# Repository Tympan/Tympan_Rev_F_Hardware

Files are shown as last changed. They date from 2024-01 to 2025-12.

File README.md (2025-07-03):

# Tympan Rev F Hardware
Tympan Rev F Hardware Design Files For First Production Run, Februrary, 2024.

Tympan is Certified Open Source Hardware!

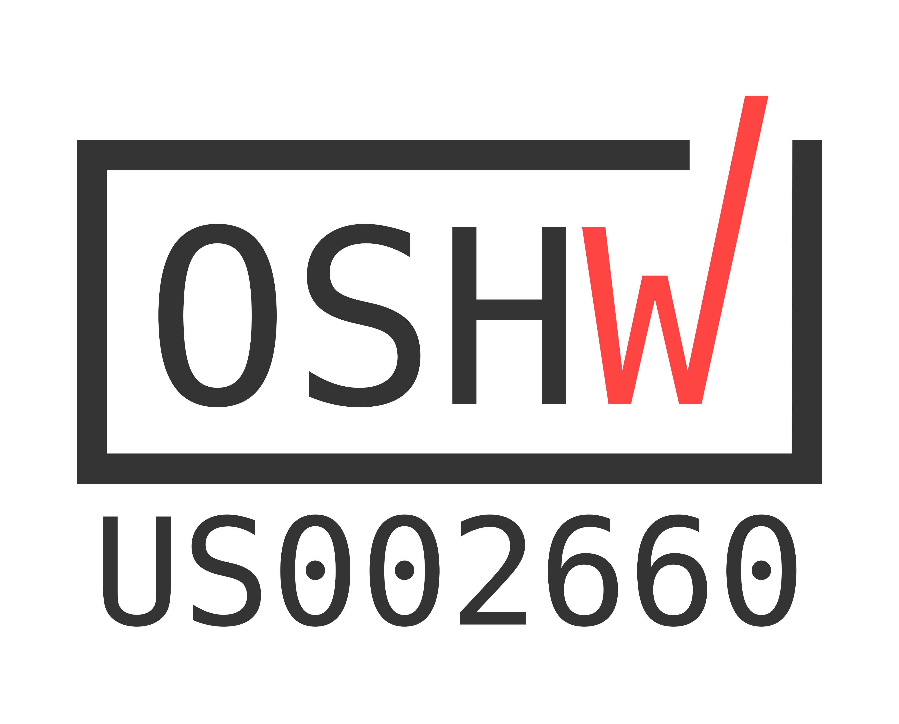
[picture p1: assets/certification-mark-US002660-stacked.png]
Certification Mark


## Changes From Rev E
For the most part, the design of Rev F is a clone of Rev E. The primary challenge of producing Rev E is that the BC127 BLE Radio module we used is not longer available (Product End Of Life). Here are the major changes in the hardware

- Changed to nRF52840 BLE Radio Module
	- Using part number MDBT50Q-1MV2 from Raytac
	- Module requires bootloader, we use Adafruit Feather nRF52840 Express bootloader
	- Bootloading blank module proceedure see below
- nRF52 does not support analog audio, but evidence exists that it can use I2S
	- I2S connections between Teensy 4.1 and nRF52 on I2S_2 pins
- UART coms with the BC127 were slower than desired
	- The SPI_1 bus is connected to nRF module for higher speed
	- The UART pins are still connected and the default speed is now 115200 bps (instead of earlier Tympan's defaulting to 9600)

# Pinout of Expansion Headers

Like all previous Tympan revisions, the Rev F has expansion headers to allow the addition of add-on boards, such as the Tympan AIC shield.  The pinout for the expansion headers is identical for Rev F as for previous Tympan revisions.  The pinout is shown in the [schematic](https://github.com/Tympan/Tympan_Rev_F_Hardware/blob/main/Tympan_Rev_F/Tympan_Rev_F_schematic.pdf) as headers P1 through P4.  You can also see the pinout below.





# Programming The Radio Module

## Over The Air Firmware Updates
Any updates to the application software can be done over Bluetooth using Over The Air Device Firmware Update (OTA DFU). This tutorial will use Adafruit's Bluefruit Connect app, which is available for iPhone and Android.

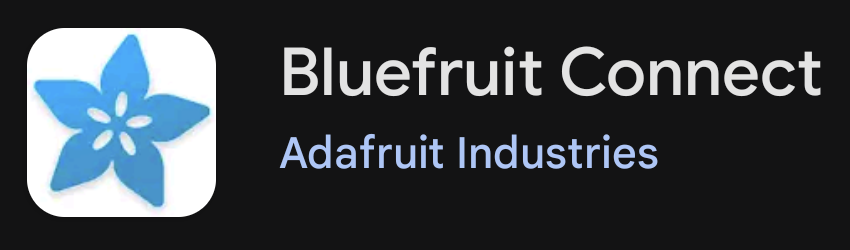
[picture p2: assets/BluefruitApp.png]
Bluefruit App


You will also need two files to upload which Arduino makes when. One is the `.hex` file, The other is a `.dat` file. The latest version of our Tympan Radio firmware is published as a release on this repository, which you can download [HERE](https://github.com/Tympan/Tympan_Rev_F_Hardware/releases/latest) The link will take you to the latest release of the firmware. Download the .ZIP file that is linked there. Both of these files need to be accessible on the phone, or tablet, that you intend to use to perform the OTA DFU. When you have the files on your mobile device, open up the Bluefruit App, and connect to the Tympan that you want to update. Each Tympan advertises it's name followed by a unique ID. Click on connect.

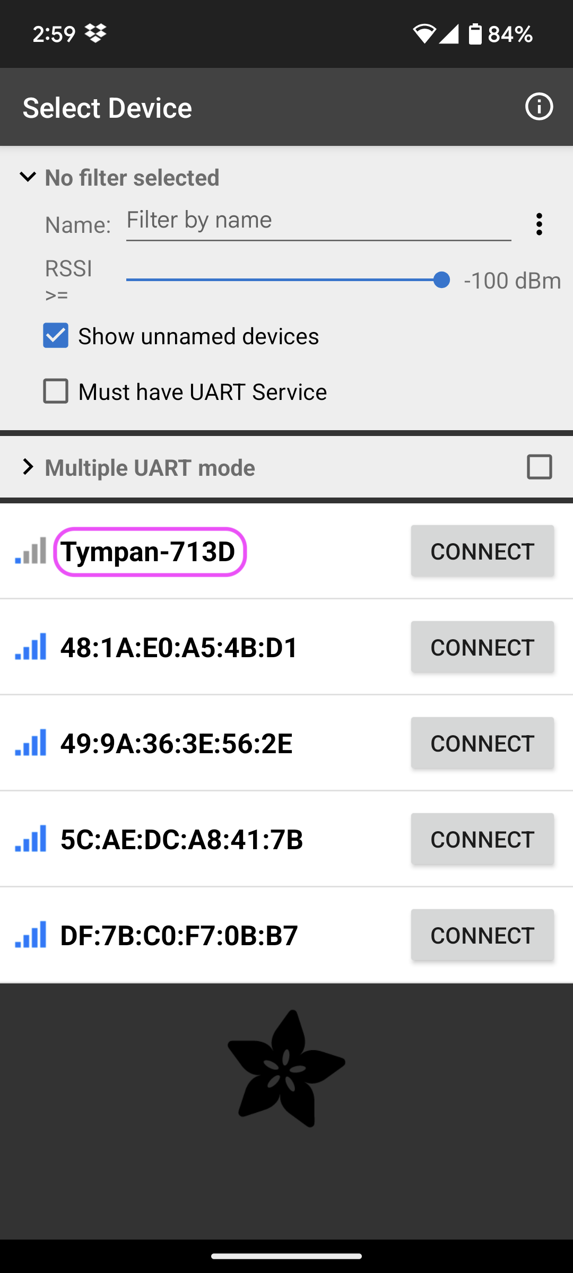
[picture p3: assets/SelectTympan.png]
Connect to Tympan


After connecting, the app will show you various tools. Scroll to the bottom and select the Updates tool.

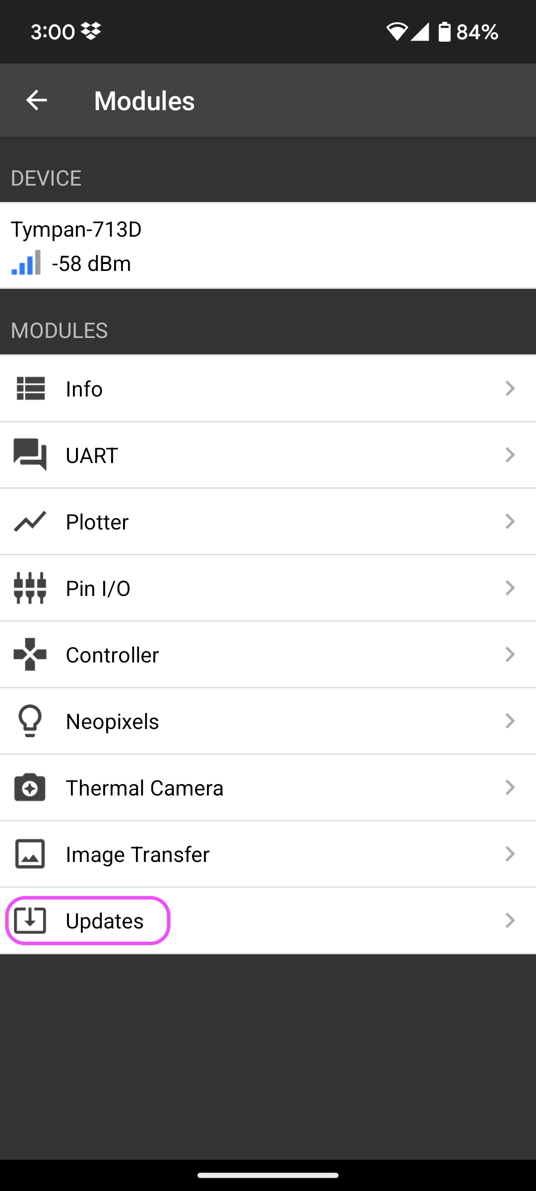
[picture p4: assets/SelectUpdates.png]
Select Updates


There is a long list of updates that are for Adafruit's BLE products. Scroll all the way to the bottom and select Custom Firmware.

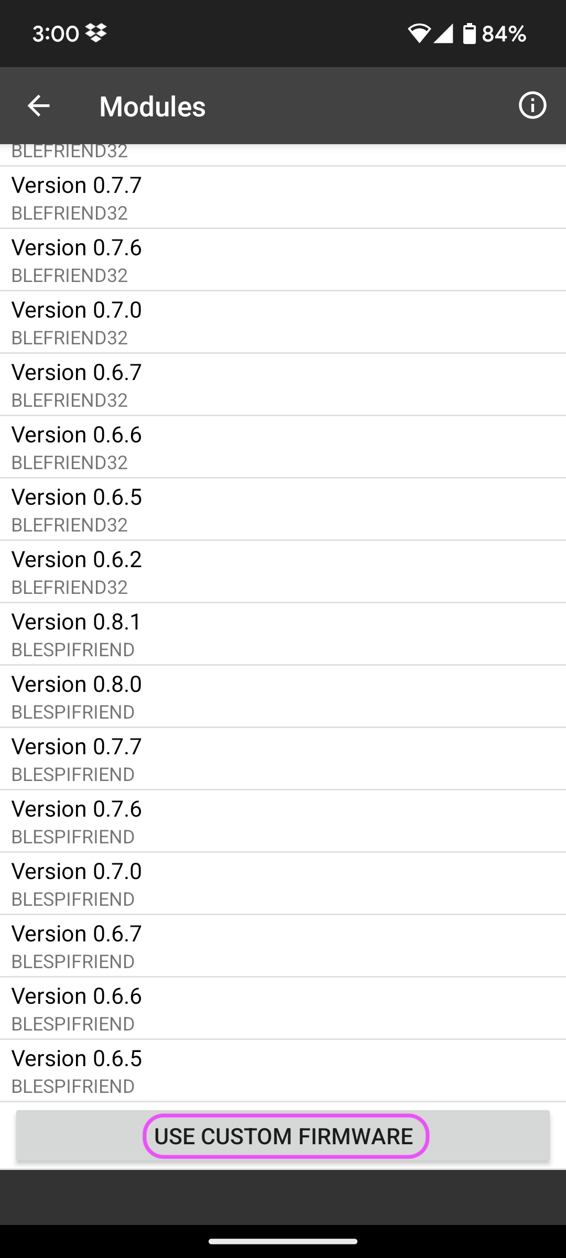
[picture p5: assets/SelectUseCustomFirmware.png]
Select Custom Firmware


The pop-up window will ask you to choose the Hex and Init files. Navigate to the place where you have stored the files you downloaded from our latest release. Choose our hex file for the .hex, and our dat file for the Init file. When you press START UPDATE, the process will begin, and the upload will show a progress bar.

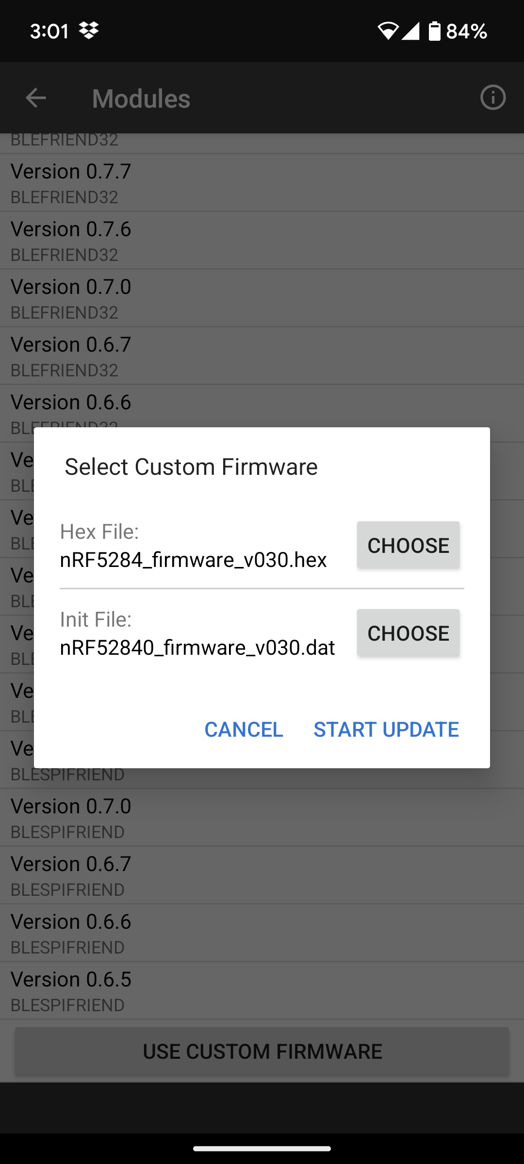
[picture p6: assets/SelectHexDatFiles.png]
Upload Progress


That's it! After successful upload, your Tympan Radio will be running the latest and greatest firmware version. If you want to continue to use the Bluefruit App, it is advised to close the close it after the upload process is complete, and then restart if you intend to use it again right away.

# Wired Firmware Updates

**NOTE: This method is included here for completion. OTA DFU should suffice of all updates**

The blank nRF52 module is programmable using the j-Link connection on pins SWO, SWCLK, SWDIO, RESET, 3V3, and GND. Those module pins are broken out to a header row on the bottom of the board. See connector J7 in the schematic, and the 6 SMT pads on the back layer of the PCB design.

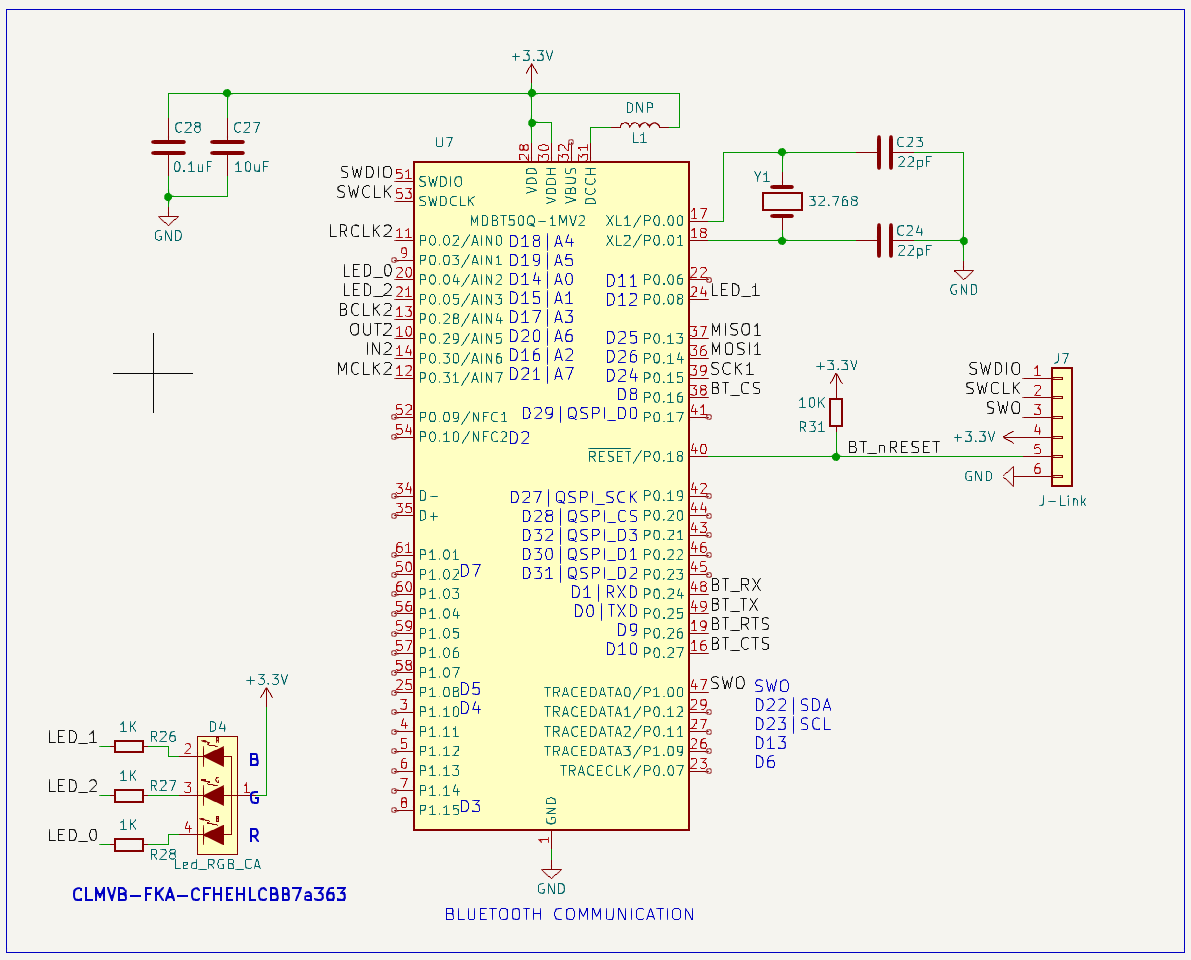
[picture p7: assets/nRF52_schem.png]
nRF52 shematic

-
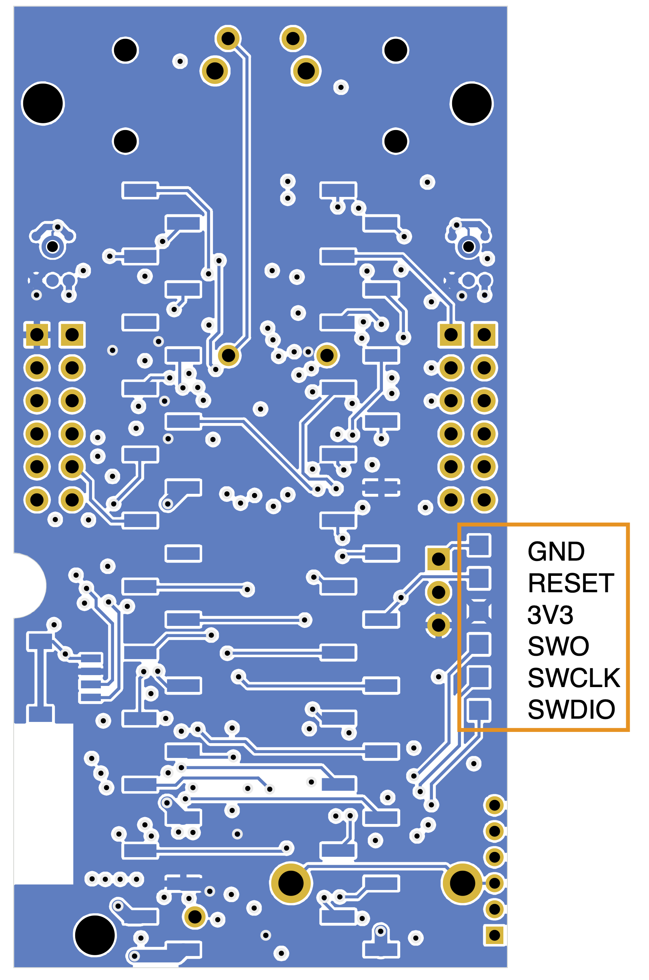
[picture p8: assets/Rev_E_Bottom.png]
J-Link Pads


### Programming Fixture

We have a specific PCB card for bootloading and programming the nRF52 The folder called `Tympan nRF52 Programmer` contains design files for this PCB. This PCB is not 100% necessary for bootloading and programming the radio. As long as you make the correct connections between the J-Link programmer and the 6 pads on the bottom of the board, you will have success using the How To Program instructions below.

### Programmer

The J-Link by Segger is preferred for flashing the bootloader and any application layer onto the nRF52. You can get one from various suppliers. [Adafruit](https://www.adafruit.com/product/2209), [Mouser](https://www.mouser.com/ProductDetail/Segger-Microcontroller/8.08.00?qs=jA5Ki6243on%2Fr15wFqMuRQ%3D%3D), [Digikey](https://www.digikey.com/en/products/detail/segger-microcontroller-systems/8-08-28/4476087) all carry them.

Adafruit also sells a [low-cost J-Link](https://www.adafruit.com/product/3571) for educational purposes. The EDU version is specifically not for use in commercial applications. If you need to re-program your radio from the bootloader up, your personal use of the EDU version will not break that rule!

## Programming With Hardware Connection

There are a couple of routes through different toolchains that are available to bootload the nRF52 module using the J-link. Our current method uses Command Line Tools from Nordic, the makers of the nRF52 chipset. Download the [Command Line Tools](https://www.nordicsemi.com/Products/Development-tools/nrf-command-line-tools/download), and install them to `Program Files (x86)`. You will also need one element of the Adafruit nRF52 toolset, which means that you need to install it through the Arduino IDE, as described in the section below "Compiling the Firmware".

**>>> NOTE: This tutorial currently only supports Windows OS**

The other software that you need is Arduino IDE, which is assumed to be installed and updated to the latest version. Arduino will very tidily create the proper compiled files for flashing. Click on `Sketch > Export Compiled Binary` and the IDE will create a folder called `build` inside your Sketch folder. The build folder contains a subfolder specific to the board. Click on `Sketch > Show Sketch Folder` to open it in an explore window. Inside the subfolder you will find 4 files.

- ELF
- HEX
- MAP
- ZIP

Each file is used for different Device Firmware Update (DFU) processes. For the purpose of initial flashing via J-Link, we will use the `.hex` file. You may note that the full name of the file is something like `TympanRadio_baseFirmware.ino.hex`. The inclusion of the .ino in the name should not cause a problem, but if you want you can change the name and remove the .ino. Just make sure to keep the .hex suffix.

We will be flashing a blank nRF52 module with Adafruit's Feather Express bootloader variant. The file we need is a `.hex` file, and it is located in `C:\Users\{USERNAME}\AppData\Local\Arduino15\packages\adafruit\hardware\nrf52\1.6.0\bootloader\feather_nrf52840_express\feather_nrf52840_express_bootloader-0.8.0_s140.6.1.1.hex`. We recommend making a copy of it, and moving it into the same folder that the IDE just made to keep things tidy.

Open a Command Prompt window, and navigate to `C:\Program Files (x86)\Nordic Semiconductor\nrf-command-line-tools\bin`, and then enter the following commands:

`nrfjprog --program {PATH}\feather_nrf52840_express_bootloader-0.8.0_s140_6.1.1.hex --format NRF52 --chiperase --reset && nrfjprog --memwr 0xFF000 --val 0x01 && nrfjprog --reset --program {PATH}\TympanRadio_baseFirmware.ino.hex --sectorerase --format NRF52 --verify --log`

The first command flashes the bootloader and the Bluetooth soft device. The second command sets a bit in 0xFF000 in order to bypass 'virgin program' hurdle. The third command programs the application software. 

## Compiling the Firmware
Ideally, you do not need to compile the firmware; you would just use the pre-compiled HEX file already included with this repository.  But, if you do need to re-compile:
* Install the Arduino IDE.
* Via the Arduino "Boards Manager", install support for "Adafruit nRF52".
  * In the Arduino IDE, go under the File menu and choose "Preferences"
  * Under "Additional Board Manager URL", add https://adafruit.github.io/arduino-board-index/package_adafruit_index.json
  * Restart the Arduino IDE
  * Open the Boards Manager from the Tools -> Board menu and install "Adafruit nRF52 by Adafruit" (this might take a few minutes)
* Clone this "Tympan Rev F Hardware" repo to your local computer
 
Once everything is installed, use the Arduino IDE to open "nRF52840_firmware.ino" that is here in the Tympan Rev F repository.  You need to tell the Arduino IDE what hardware you are programming for:
* Under the "Tools" menu, choose "Board" and set it to "Adafruit Feather nRF52840 Express".

Now you can make any changes you want to the code.  When done, compile.  The Arduino IDE cannot upload the firmware directly to the nRF58240 in the Tympan.  Instead, you must use the "hardware connection" or "over the air" methods described in the sections above. To get the HEX and DAT files for these methods:
* In the Arduino IDE, under the "Sketch" menu, choose "Export Compiled Binary"

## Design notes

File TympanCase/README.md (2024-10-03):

# Tympan Rev F Enclosure

Here find STL files for printing the Tympan Rev F case.
Production cases were printed on a Lulzbot Taz Mini2 in PLA plastic. The bottom is printed in [Turquoise Green](https://www.matterhackers.com/store/l/fillamentum-pla/sk/M48DW96N), and the top is printed in [Pistachio Green](https://www.3dfuel.com/collections/285/products/standard-pla-filament-pistachio-green-2-85mm).

Further notes on hardware used

- [M2.5 x 0.45mm Brass Threaded Insert](https://www.mcmaster.com/catalog/94459A439)
- [6-32 x 0.18"L Brass Threaded Insert](https://www.mcmaster.com/97171A130)
- [M2.5 x 0.45mm x 10mm Oval Head Screw](https://www.mcmaster.com/90258A115)
- [6-32 x 1/4" Truss Head Screw](https://www.mcmaster.com/94792A416)
- [Belt Clip](https://www.theclip.com/store/metal-belt-clip-661)
- Open Cell Foam for Interior Padding

Pics coming soon!

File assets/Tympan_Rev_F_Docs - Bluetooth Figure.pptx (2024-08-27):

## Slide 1

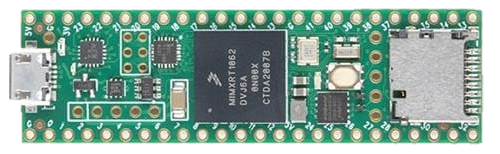
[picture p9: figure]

Teensy 4.1

Change Software via USB

Tympan Rev F

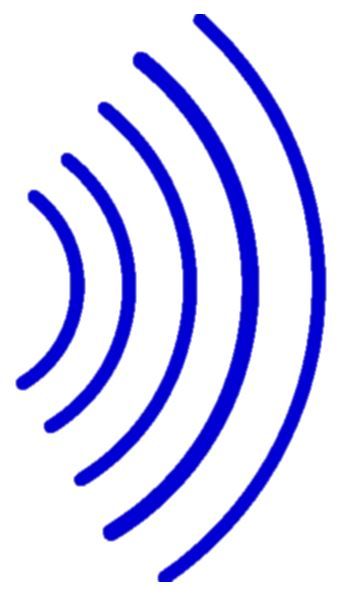
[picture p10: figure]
Radio Waves Art At Clker Com Vector - Radio Wave - Free Transparent PNG Download - PNGkey

Bluetooth (BLE)

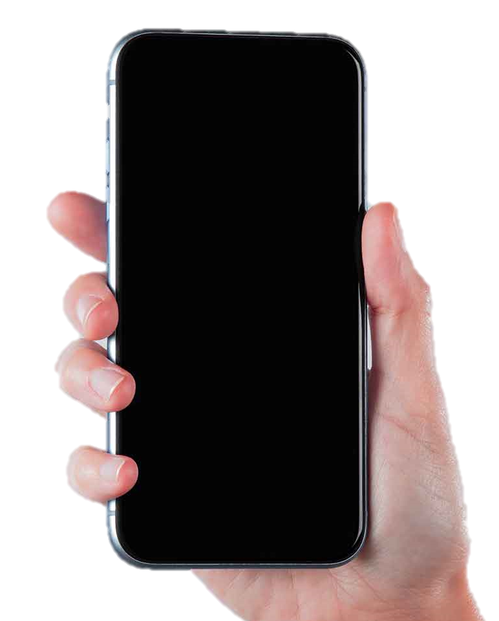
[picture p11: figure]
Free Hand Holding Smartphone Mockup (PSD)

Serial (UART)

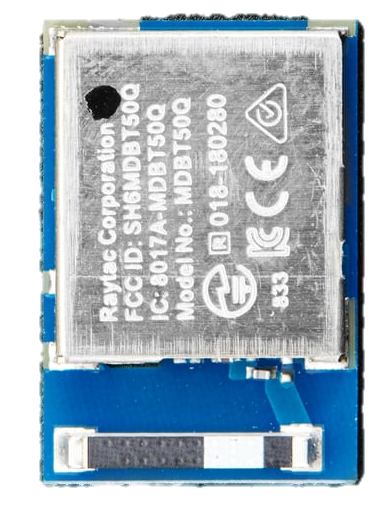
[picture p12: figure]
Top down view of a nRF52840 Bluetooth Low Energy Module with USB.

nRF52840

Change Firmware via J-Link (or OTA)

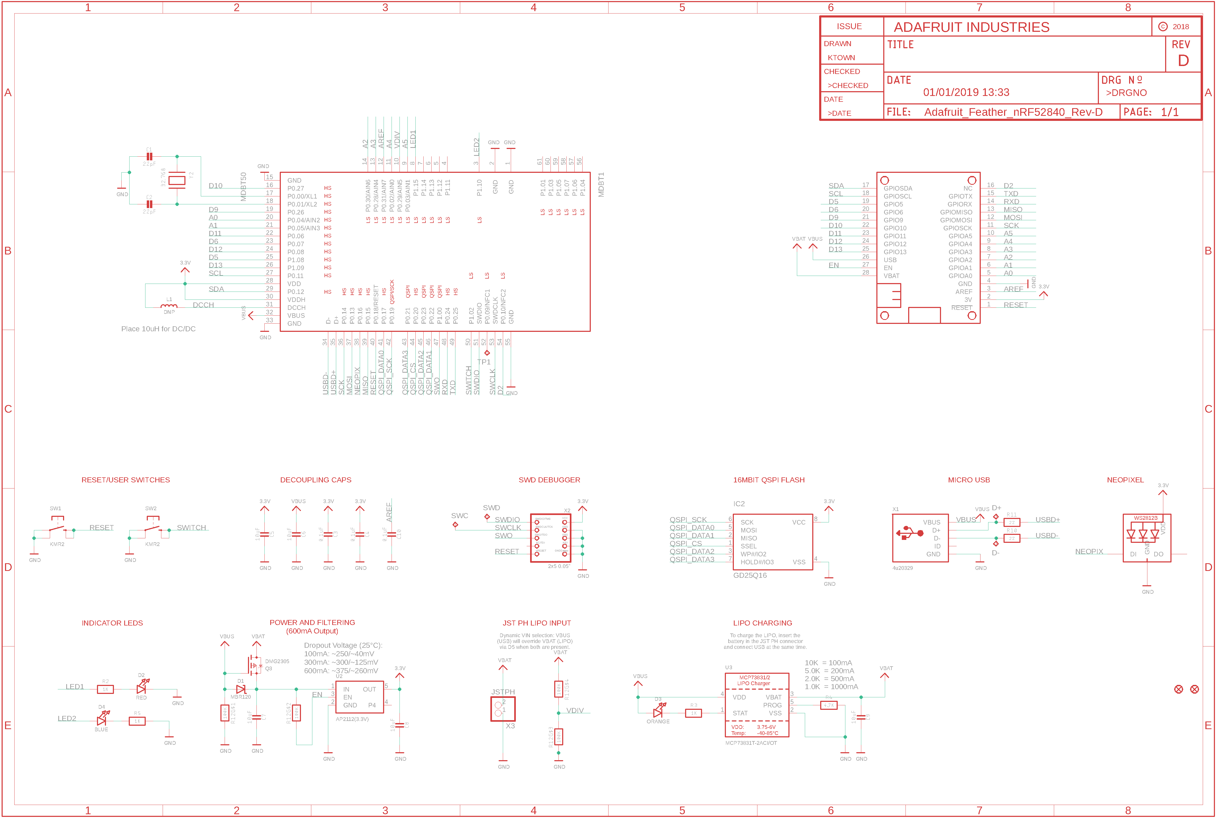
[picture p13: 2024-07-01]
assets/adafruit_nRF52840_Schematic_REV-D.png

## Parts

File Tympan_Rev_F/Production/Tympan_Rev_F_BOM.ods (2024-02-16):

 | Tympan Rev F BOM
 | Component Count: | 86
Item | Ref | Qnty | Value | Cmp name | Manufacturer | Part Number | Notes
1 | BT1 | 1 | Battery_Cell | Battery_Cell | Keystone | 3001
2 | BT2 | 1 | 4UCON-20519 | Battery_Cell | 4UCON | 0217-20519 | Consigned
3 | C1, C2, C3, C4, C5, C11, C15, C16 | 8 | 2.2uF | C_Small | Murata | GRM155R61E225ME15D
4 | C6, C8, C10, C13, C17, C18, C25, C28 | 8 | 0.1uF | C | Samsung | CL05B104KO5NNNC
5 | C7, C9, C14, C27 | 4 | 10uF | C | Samsung | CL05A106MP5NUNC
6 | C12, C19, C20, C21, C22, C26 | 6 | 1uF | C_Small | Samsung | CL05A105KO5NNNC
7 | C23, C24 | 2 | 22pF | C | Murata | GCM1555G1H220JA16D
8 | D1 | 1 | APHB1608SGNC | APHB1608SGNC | Kingbright | APHB1608CGKSURKC
9 | D2 | 1 | Red LED | LED | Wurth | 156120RS75000
10 | D3 | 1 | Green LED | LED | Wurth | 156120VS75000
11 | D4 | 1 | Led_RGB_CA | Led_RGB_CA | Wolfspeed | CLMVC-FKA-CLBDGL7LBB79353
12 | F1 | 1 | FUSE | Fuse | Bel Fuse | C1Q 750
13 | J1 | 1 | SJ-3523-SMT-TR | SJ-3523-SMT-TR | CUI Devices | SJ-3523-SMT-TR
14 | J2 | 1 | SJ-3524-SMT-TR-PI | SJ-3524-SMT-TR-PI | CUI Devices | SJ-3524-SMT-TR-PI
15 | J3 | 1 | Conn_01x06 | Conn_01x06 | DNP | DNP | DNP
16 | J4 | 1 | Qwiik Connector | Conn_01x04 | SparkFun | PRT-14417
17 | J7 | 1 | J-Link | Conn_01x06 | DNP | DNP | DNP
18 | L1 | 1 | DNP | L | DNP | DNP | DNP
19 | MIC1, MIC2 | 2 | SPM0687LR5H-1 | SPM0687LR5H-1 | Knowles | SPM0687LR5H-1
20 | P1, P2, P3, P4 | 4 | CONN_01X06 | Conn_01x06 | Samtec | SSW-106-01-T-S
21 | R1, R11, R26, R27, R28 | 5 | 1K | R_Small | Yageo | RC0402FR-071KL
22 | R2, R16, R17 | 3 | DNP | R_Small | DNP | DNP | DNP
23 | R3, R4, R5, R6, R7, R8, R9, R10 | 8 | 33R | R_Small | Yageo | RC0402FR-0733RL
24 | R12 | 1 | 2.2K | R_Small | Yageo | RC0402FR-132K2L
25 | R13, R14 | 2 | 0R | R_Small | Yageo | RC0603JR-070RL
26 | R15, R18 | 2 | 2.2K | R_Small | Yageo | RC0603FR-072K2L
27 | R19, R20 | 2 | 240R | R_Small | Yageo | RC0402FR-07240RL
28 | R29, R30, R32, R33 | 4 | 4K7 | R_Small | Yageo | RC0402FR-074K7L
29 | R31 | 1 | 10K | R_Small | Yageo | RC0402FR-0710KL
30 | RV1 | 1 | POT | R_Potentiometer_US | Bourns | 3352T-1-504LF
31 | SW1 | 1 | CL-SB-22A | CL-SB-22A | Nidec Copal | CL-SB-22A-11T
32 | SW2 | 1 | SW_Push | SW_Push | APEM | MJTP1117
33 | U1 | 1 | MCP73831 | MCP73831 | Microchip | MCP73831T-2ACI/OT
34 | U2 | 1 | TLV320AIC3206IRSBT | TLV320AIC3206IRSBT | Texas Instruments | TLV320AIC3206IRSBT
35 | U3 | 1 | 74LVC1G66 | 74LVC1G66 | Texas Instruments | TS5A4594DCKRE4
36 | U4 | 1 | LP5907MFX-1.8 | LP5907MFX-1.8 | Texas Instruments | LP5907MFX-1.8/NOPB
37 | U5 | 1 | Teensy4.1 | Teensy4.1 | Consigned | Consigned | Consigned
38 | U6 | 1 | LC709203 | LC709203 | DNP | DNP | DNP
39 | U7 | 1 | MDBT50Q-1MV2 | MDBT50Q-1MV2 | Raytac | MDBT50Q-1MV2
40 | Y1 | 1 | 32.768 | Crystal | Microchip | VMK3-9001-32K7680000

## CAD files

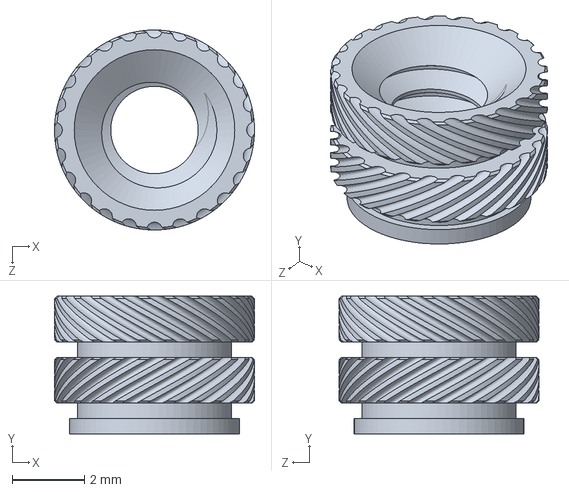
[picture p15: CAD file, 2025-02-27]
TympanCase/2025-0227_Tympan-Rev-F_Case_Solidworks_2023/HEAT-SET INSERT_6-32_SHORT_MMC_94459A280.SLDPRT
5.54 x 3.81 x 5.54 mm

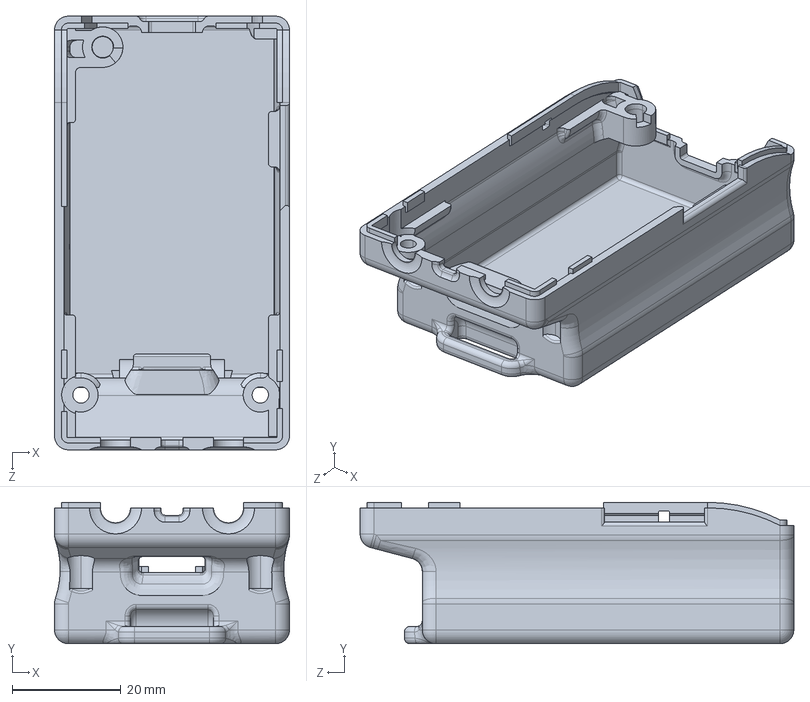
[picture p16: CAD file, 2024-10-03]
TympanCase/7146_Tympan_Rev-F_Bottom_Case.STEP
43.2 x 26.0 x 79.8 mm

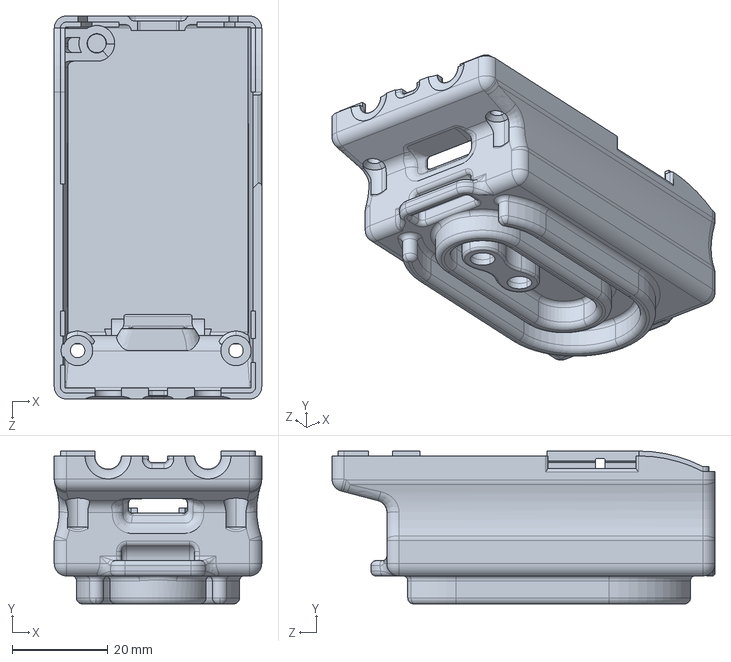
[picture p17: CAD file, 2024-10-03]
TympanCase/Alternate_Case_W_Belt_Clip_Holes/7146_Tympan_Rev-F_Bottom_Case_Belt_Mount.STEP
43.2 x 31.9 x 79.8 mm

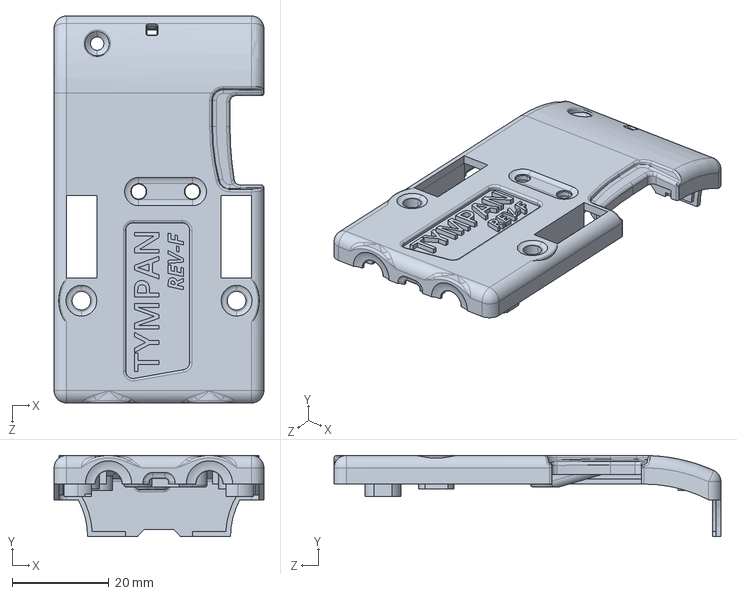
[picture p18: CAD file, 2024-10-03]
TympanCase/7146_Tympan_Rev-F_Top_Case.STEP
43.2 x 16.7 x 79.8 mm

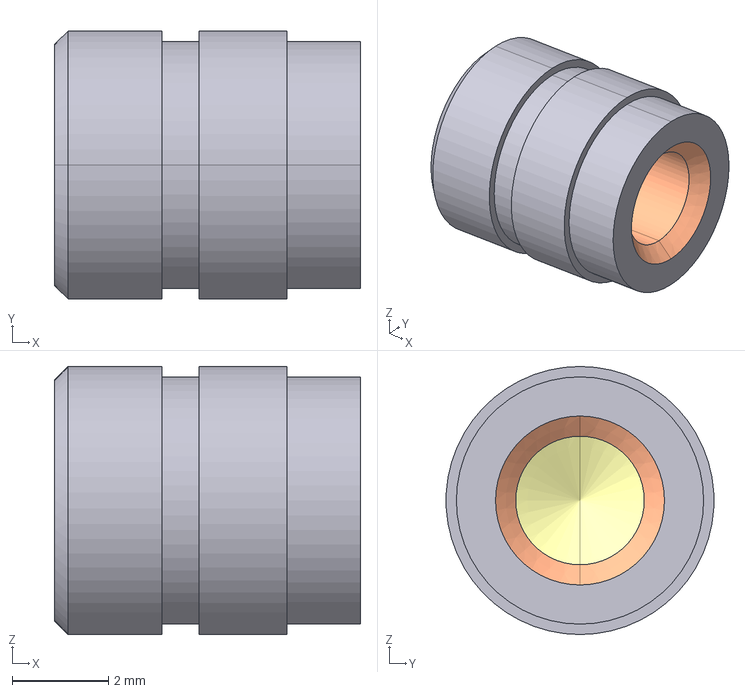
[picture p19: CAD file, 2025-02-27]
TympanCase/2025-0227_Tympan-Rev-F_Case_Solidworks_2023/IBB-632-4-PennEngineering-3D-08-30-2024.stp
6.35 x 5.55 x 5.56 mm

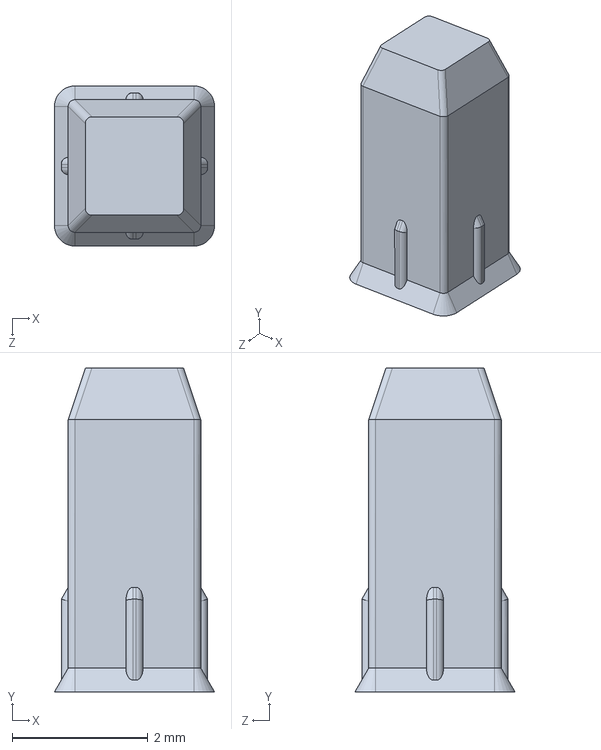
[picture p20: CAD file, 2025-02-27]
TympanCase/2025-0227_Tympan-Rev-F_Case_Solidworks_2023/Lightpipe_2mm_SQ_0188LG_Countersunk_Bivar_PLPQ2-188-FF.SLDPRT
2.36 x 4.78 x 2.36 mm

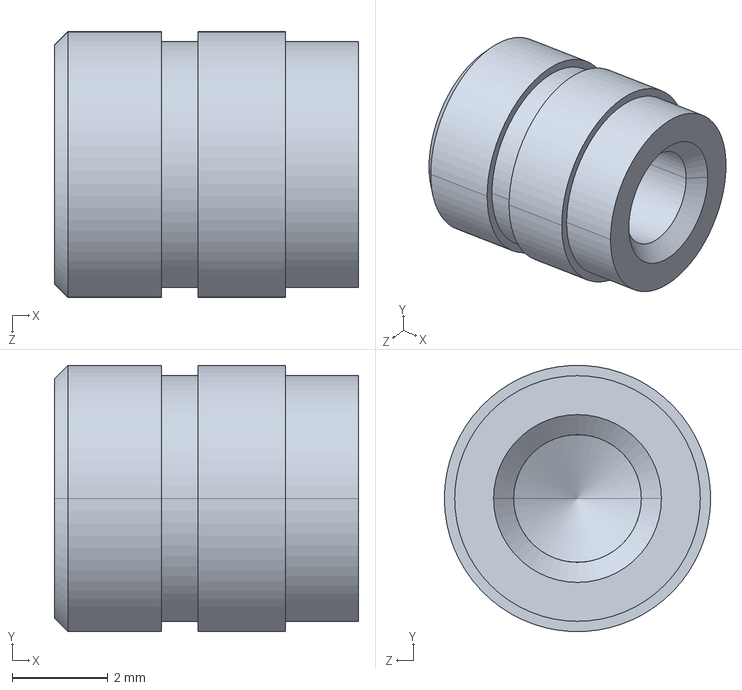
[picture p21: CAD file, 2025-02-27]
TympanCase/2025-0227_Tympan-Rev-F_Case_Solidworks_2023/HEAT-SET INSERT 6-32_CLOSED_PENN_IBB-632-4.SLDPRT
6.35 x 5.56 x 5.56 mm

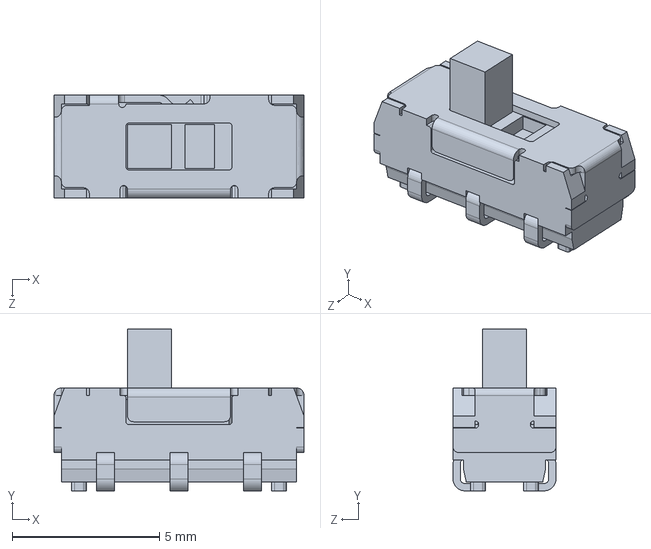
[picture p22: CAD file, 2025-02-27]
TympanCase/2025-0227_Tympan-Rev-F_Case_Solidworks_2023/SWITCH_2POS_VERT_NIDEC_CL-SB-22A-01T.SLDPRT
8.50 x 5.50 x 3.50 mm

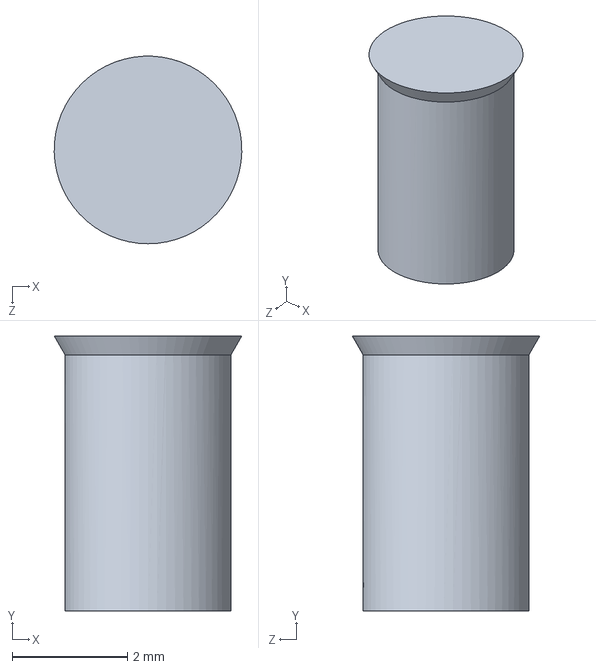
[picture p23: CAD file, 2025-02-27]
TympanCase/2025-0227_Tympan-Rev-F_Case_Solidworks_2023/Lightpipe_3mm-dia_0188in_CounterSink_BIVAR_51513130188F.SLDPRT
3.25 x 4.76 x 3.25 mm

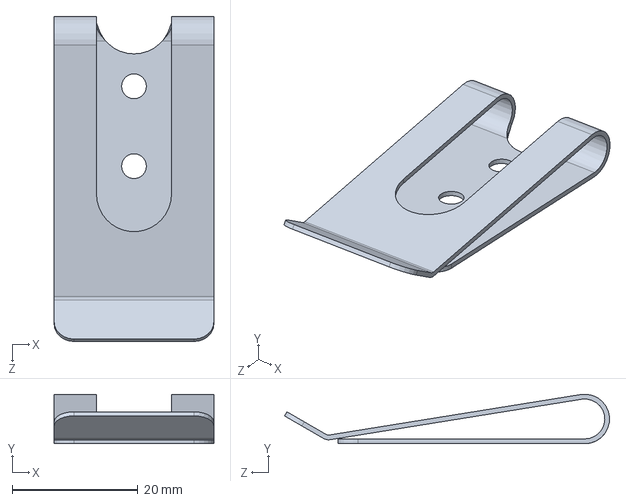
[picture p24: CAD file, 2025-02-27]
TympanCase/2025-0227_Tympan-Rev-F_Case_Solidworks_2023/BELTCLIP__MCS-661BP.SLDPRT
25.4 x 7.86 x 51.7 mm

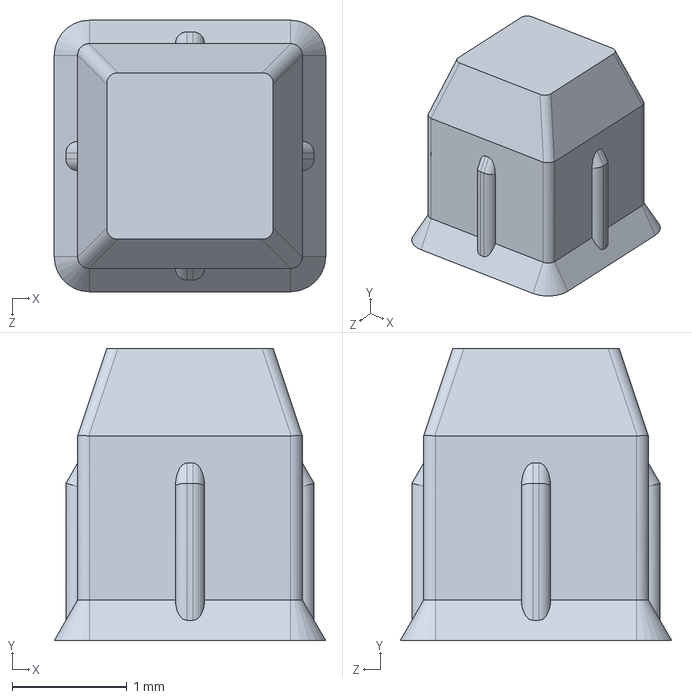
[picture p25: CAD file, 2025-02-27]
TympanCase/2025-0227_Tympan-Rev-F_Case_Solidworks_2023/Lightpipe_2mm_SQ_0100LG_Countersunk_Bivar_PLPQ2-100-FF.SLDPRT
2.36 x 2.54 x 2.36 mm

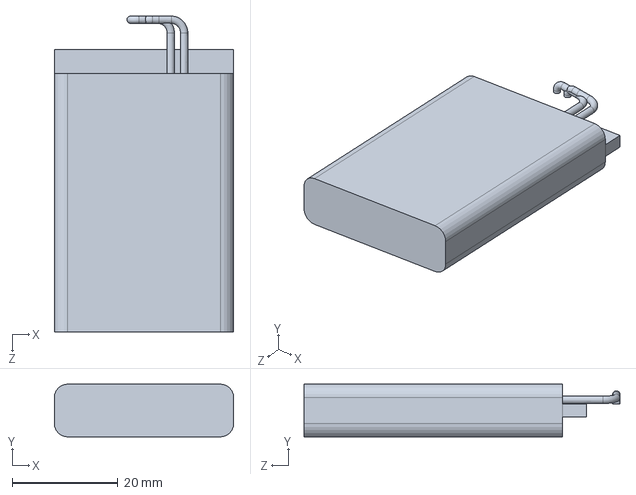
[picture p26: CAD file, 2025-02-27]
TympanCase/2025-0227_Tympan-Rev-F_Case_Solidworks_2023/BATTERY_JOEL_IMPORT_2000MAH_103450.SLDPRT
34.0 x 10.0 x 59.9 mm

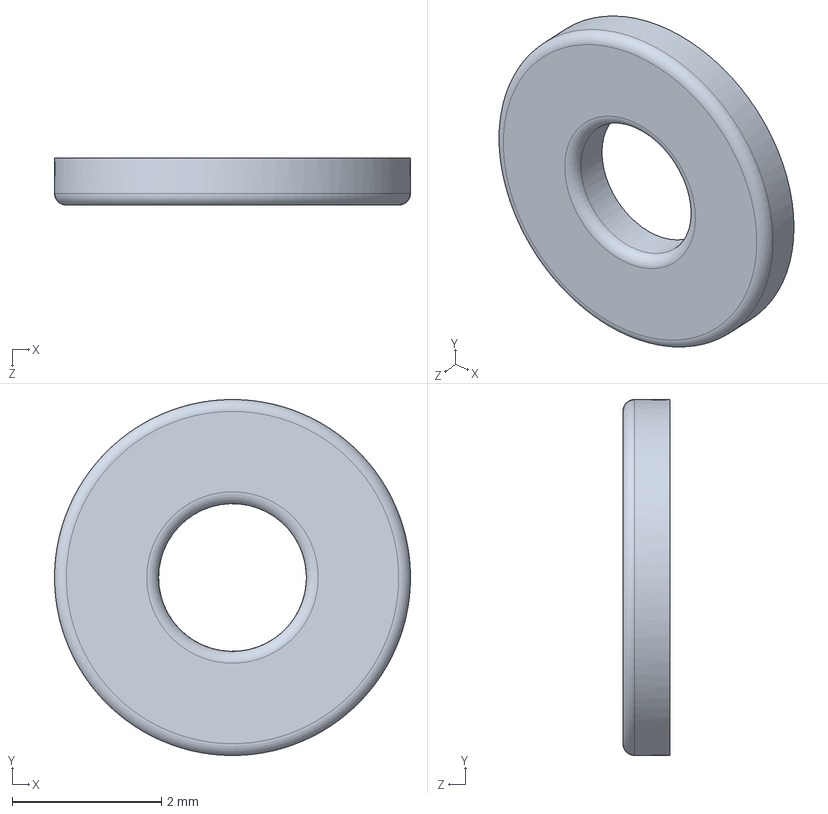
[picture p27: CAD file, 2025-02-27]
TympanCase/2025-0227_Tympan-Rev-F_Case_Solidworks_2023/90107A002_316 Stainless Steel Washer_Sz-0.SLDPRT
4.78 x 4.78 x 0.635 mm

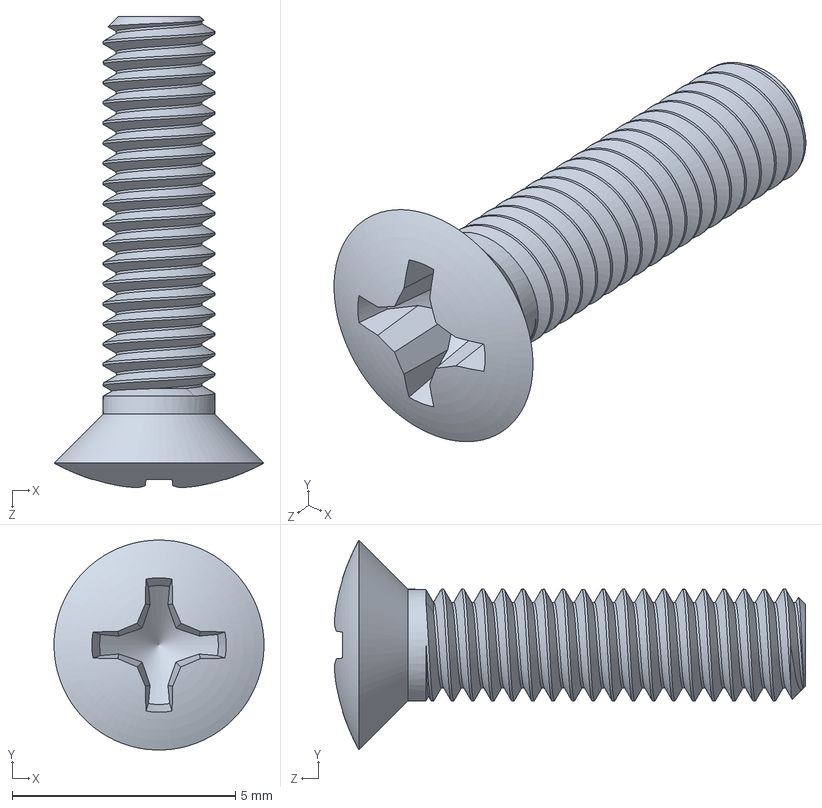
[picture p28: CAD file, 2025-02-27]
TympanCase/2025-0227_Tympan-Rev-F_Case_Solidworks_2023/SCREW_PH-OVAL_M2500_045_10MM_LG_SS_MCMASTER_90258A115.SLDPRT
4.70 x 4.70 x 10.6 mm

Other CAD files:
TympanCase/Alternate_Case_W_Belt_Clip_Holes/7146_Tympan_Rev-F_Top_Case_Belt_Mount.STEP
TympanCase/7146_Tympan_Rev-F_Top_Casel.STL
TympanCase/2025-0227_Tympan-Rev-F_Case_Solidworks_2023/TRUSS HEAD PHILLIPS SCREW_6-32_0188LG.SLDPRT
TympanCase/2025-0227_Tympan-Rev-F_Case_Solidworks_2023/94180A321_HEAT-SET_INSERT_M2.5-045.SLDPRT
TympanCase/2025-0227_Tympan-Rev-F_Case_Solidworks_2023/86375K131_NEOPRENE_031_THK.SLDPRT
TympanCase/2025-0227_Tympan-Rev-F_Case_Solidworks_2023/90258A121_Phillips Oval Head Screws.SLDPRT
TympanCase/2025-0227_Tympan-Rev-F_Case_Solidworks_2023/91755A325_RETAINING_WASHER_M2-5.SLDPRT
TympanCase/2025-0227_Tympan-Rev-F_Case_Solidworks_2023/94459A439_HEATSET_INSERT_M2.5.SLDPRT
TympanCase/7146_Tympan_Rev-F_Bottom_Case.stl
TympanCase/Alternate_Case_W_Belt_Clip_Holes/7146_Tympan_Rev-F_Bottom_Case_Belt_Mount.STL
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

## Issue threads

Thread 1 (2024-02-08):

RTC Battery Life

biomurph, 2024-02-08:
I saw that the recommended coin for RTC is 2032 (20mm diameter).
We currently use 12mm diameter 1225. the difference is
2032 ~220mAh
1225 ~40mAh.

Then poking the form, I saw these posts
https://forum.pjrc.com/index.php?threads/teensy-4-x-rtc-battery-life.68148/
https://forum.pjrc.com/index.php?threads/beware-t4x-rtc-power-consumption.64216/#post-257979

tldr: Expected battery life in days on the Teensy 4.1

Days @30uA
CR1220 = 50
CR2032 =  305
CR2450 =  833

That is not long, even for the 2032, given we have these in the field. Are we getting any feedback on this from users?

chipaudette, 2024-02-09:
I haven't heard any feedback, either way.

I would support using a higher capacity coin cell, but they are so much bigger that I bet it'll l be too hard to fit.

biomurph, 2024-02-12:
PJRC recommends a 2032 coin cell (20mm dia, 3.2mm thick).
Just can't fit that diameter on the board.
At least it's easy to replace?

chipaudette, 2024-02-13:
The army users are used to the Rev D, which presumably had a much longer RTC battery life.  Ive become more fearful that this short life with Rev E will cause them disappointment.

On the teensy forum thread about the high RTC power consumption, folks talked about switching back to an i2c RTC instead of using the built in rtc.  One individual talked about the "I2C RTC - RV-3028-C7".  Or, I think that there are a few qwiic RTC from sparkfun.

@biomurph, Have you used any of these before?

biomurph, 2024-02-13:
Yes, I have used RTC modules and also incorporated RTC chips in projects.
Here are some examples
https://www.adafruit.com/product/3028
https://www.adafruit.com/product/5188
SparkFun also has a bunch. Many with the Qwiic | Stemma connections.

I guess another route would be to use a rechargable coin cell, and incorporate it into the charging circuit that we already have?

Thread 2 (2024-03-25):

BLE Radio OTA DFU Only Works With Adafruit Bluefruit Connect App?

biomurph, 2024-03-25:
It has been the case that the only OTA DFU process that completed successfully has been done with the Adafruit Bluefruit Connect  App. This thread will record the results of testing OTA DFU using various methods. Each test begins with a radio module that is direct from production testing, flashed with the TympanRadio_baseFirmware.ino sketch.

OTA DFU variables include
Operating System
* iOS
* Android
File Base Used
* Arduino IDE Menu Select: Sketch > Export Compiled Binary
* Arduino IDE .zip file created during normal compilation process
App Used
* Adafruit Bluefruit Connect App
* nRF Toolbox App or nRF Connect App

## Android OS
Tested using Google Pixel 6
* Adafruit Bluefruit App uploads OTA successfully
* Nordic nRF Toolbox App
  * Fails using Arduino Export Compiled Binary after DFU Initialization, at the beginning of the upload process
  * Fails using Arduino zip created during compilation after DFU Initialization, at the beginning of the upload process
* Nordic nRF Connect App
  * Fails using Arduino Export Compiled Binary after DFU Initialization, at the beginning of the upload process
  * Fails using Arduino zip created during compilation after DFU Initialization, at the beginning of the upload process

Successful OTA DFU is possible, but only via the Adafruit Bluefruit App.
I uploaded 3 times in a row with 3 times success.

chipaudette, 2024-03-25:
I still can't get Adafruit Bluefruit Connect to accept any of the file managers on my phone.  I have both the default google "Files", I have Google Drive, and I downloaded (per the Adafruit error message) Dropbox.  No joy.

I went into the settings for Bluefruit Connect and made sure that I was allowing access to "media and files".  Still, no success.

Specific error is "Unavailable.   File browser app not [sic] has not been found on your device.  You should install an app like Dropbox, GoogleDrive..."

Googling this error only reveals the GitHub repo for this App.  I had been hoping a Adafruit forum posting might show up in the Google results.  Nope.  :(

biomurph, 2024-03-26:
@chipaudette Are you able to test with a different phone?
I will test with my burner today. It is an LG phone, I think.

chipaudette, 2024-03-26:
I just tested with my ancient phone via the Adafruit app.  Unlike on my normal phone, it correctly found a File Browser App, so I was able to select the HEX and DAT files.  Unfortunately, it failed to get very far in the actual update process.   :(

This was for your nRF52840 stand-alone board, not a Rev F.  I'm a little hesitant to try this on a Rev F as we risk locking up its nRF unit until we get the nest working.  But, I suppose that I ought to give it a try anyway?  What do you think?

biomurph, 2024-03-26:
I have always been able to bring the nRF51 back to life with the bed of nails and the J-Link. That process erases the whole chip and starts from scratch.
You should get email notifications from USPS about the package shipping and arrival at Creare.

biomurph, 2024-03-27:
Unfortunately, I am unable to load Bluefruit Connect App on my old backup phone...
Guess I need a new backup phone...

chipaudette, 2024-03-29:
The project had an older Android phone that I was able to borrow.  It runs the update portion of the Adafruit app just fine.  I've successfully updated the firmware a couple of times.  It ain't fast, but it does the job.   Excellent.

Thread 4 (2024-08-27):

Tympan Radio BLE Configuration of Tympan-Specific Service is incompatible with Capacitor Plugin for BLE

cab-creare-com, 2024-08-27:
We are developing an Android app using the Angular framework built with Capacitor that will use BLE to talk to the Tympan Rev F, we can successfully write to the nRF UART Service, but **we get an error when our app tries to write to the Tympan-Specific Service**.   For comparison, we can successfully write to the Tympan-Specific Service on the Tympan Rev E.

On the Android side, we are using the Capacitor plugin for BLE: (https://www.npmjs.com/package/@capacitor-community/bluetooth-le/v/0.5.1).   When we attempt to write to the characteristic, the BLE library fails in the "write" attempt, reporting that the characteristic is not writable.

We are aware that the [Tympan Remote App](https://github.com/Tympan/Tympan_Remote_App) can successfully connect to the Tympan-Specific Service on both Rev E and Rev F, but that uses a 3-year-old Cordova-derived BLE library that may lose support in future Android versions.

I suspect the issue is related to the configuration of the BLE characteristics onboard the Tympan.

Here are the BLE services advertised by the Rev E and the Rev F:
[Tympan Rev E BLE Services.txt](https://github.com/user-attachments/files/16764654/Tympan.Rev.E.BLE.Services.txt)
[Tympan Rev F BLE Services.txt](https://github.com/user-attachments/files/16764683/Tympan.Rev.F.BLE.Services.txt)

Looking specifically at the Tympan-Specific Service ("uuid": "bc2f4cc6-..."), here is the line-by-line comparison:

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

Of note, the Tympan-Specific Service on the Tympan Rev F has three characteristics which share a UUID, which prevents them from being uniquely targeted by a "write" command.

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
chipaudette, 2024-08-27:
Adding "write" to the already existing "notify" seems easy enough, but you'll note that that's what the second UUID entry enables (for the same UUID).  So, it's possible that this is a "feature" of the underlying nRF52 library from Adafruit.  We'll see. The adafruit nRF52 library is (I think) mostly a wrapper around the API provided by Nordic, so hopefully we can work around it.

Another alternative is to ask the Capacitor plugin to transmit the value via Notify rather than through Write?

cab-creare-com, 2024-08-27:
I don't think it's a "feature" of the Adafruit nRF52 library, since the nRF UART Service does not have this duplicated UUID:

Here's the nRF UART Service from [Tympan Rev F BLE Services.txt](https://github.com/user-attachments/files/16764683/Tympan.Rev.F.BLE.Services.txt):
```javascript
    {
        "uuid": "6e400001-b5a3-f393-e0a9-e50e24dcca9e",
        "characteristics": [
            {
                "uuid": "6e400003-b5a3-f393-e0a9-e50e24dcca9e",
                "properties": {
                    "broadcast": false,
                    "read": false,
                    "writeWithoutResponse": false,
                    "write": false,
                    "notify": true,
                    "indicate": false,
                    "authenticatedSignedWrites": false,
                    "extendedProperties": false
                },
                "descriptors": [
                    {
                        "uuid": "00002902-0000-1000-8000-00805f9b34fb"
                    },
                    {
                        "uuid": "00002901-0000-1000-8000-00805f9b34fb"
                    }
                ]
            },
            {
                "uuid": "6e400002-b5a3-f393-e0a9-e50e24dcca9e",
                "properties": {
                    "broadcast": false,
                    "read": false,
                    "writeWithoutResponse": true,
                    "write": true,
                    "notify": false,
                    "indicate": false,
                    "authenticatedSignedWrites": false,
                    "extendedProperties": false
                },
                "descriptors": [
                    {
                        "uuid": "00002901-0000-1000-8000-00805f9b34fb"
                    }
                ]
            }
        ]
    },
```

Note that the nRF52 UART Service has a UUID = 6e40**0001**-..., and it has one (non-writeable) characteristic with UUID = 6e40**0003**-... and one (writeable) characteristic with UUID = 6e40**0002**-....

chipaudette, 2024-08-27:
Unfortunately, we might be talking about two different universes.  It looks like Joel might have pre-installed firmware on the Rev F that I was not expecting.

Currently, he said that he installed this: https://github.com/Tympan/Tympan_Rev_F_Hardware/tree/main/TympanRadio_baseFirmware

I had thought that he was using this: https://github.com/Tympan/Tympan_Sandbox/tree/master/Tympan%20Bluetooth/nRF52840%20Firmware/nRF52840_firmware

I've asked him to confirm.

One way for us to test ourselves would be to use one of the Bluetooth test programs that are part of the "Tympan_Library" examples.  Specifically, this one: https://github.com/Tympan/Tympan_Library/tree/main/examples/02-Utility/Bluetooth/Tympan_Test_BLE

Once it's running, you can use the serial menu to send a 'v' (for 'version').  If it says "TympanBLE v0.1.0", you've got the old one.  If it says "TympanBLE v0.2.4, nRF52840", you've got the new one.

chipaudette, 2024-08-27:
Here is the current code:

```
// ID Strings to be used by the nRF52 firmware to enable recognition by Tympan Remote App
uint8_t serviceUUID[] = { 0xF0, 0x28, 0xE3, 0x68, 0x62, 0xD6, 0x34, 0x90, 0x51, 0x43, 0xEF, 0xAA, 0xC6, 0x4C, 0x2F, 0xBC };
uint8_t characteristicUUID[] = {  0x3C, 0xD9, 0xF7, 0x89, 0x37, 0x37, 0xAA, 0x8F, 0x71, 0x4A , 0xAD, 0x79, 0xE7, 0xE5, 0xD1, 0x06};
BLECharacteristic myBleChar = BLECharacteristic(characteristicUUID, BLENotify | BLEWrite); //from #include <bluefruit.h>
```

Note that it invokes "Notify" and "Write" for the same characteristicUUID.  Yet, per @cab-creare-com screenshot, the "write" capability shows up as a different entry from the "notify".  Why?  I'm not sure.  Let's see how I handle this BLECharacterstic object.

First, here's where I instantiate classes to provide the four different services that we currently offer:

```
//Create the nRF52 BLE elements (the firmware on the nRF BLE Hardware itself)
BLEDfu          bledfu;  // Adafruit's built-in OTA DFU service
BLEDis          bledis;  // Adafruit's built-in device information service
BLEUart_Tympan  bleService_tympanUART;    //Tympan extension of the Adafruit UART service that allows us to change the Service and Characteristic UUIDs
BLEUart         bleService_adafruitUART;  //Adafruit's built-in UART service
```

Next, here's where I invoke the services:

```
  // Configure the standard Adafruit UART service
  bleService_adafruitUART.begin();

  // Configure and Start our custom tympan-specific BLE Uart Service
  bleService_tympanUART.setUuid(serviceUUID);
  bleService_tympanUART.setCharacteristicUuid(myBleChar);
  bleService_tympanUART.begin();

  // Start our custom service
  myBleChar.setProperties(CHR_PROPS_NOTIFY);  //is this needed?
  myBleChar.setPermission(SECMODE_OPEN, SECMODE_NO_ACCESS); //is this needed?
  myBleChar.begin();
```

The code above is mostly copy-paste, so I don't know what `CHR_PROPS_NOTIFY`, `SECMODE_OPEN`, and `SECMODE_NO_ACCESS` do.  **Maybe these three constants hold the source of the problem?**  I'm guessing that these items are defined in the Adafruit or nRF APIs, so I ought to find them fairly readily.

Finally, just for completeness, here's where I set up the BLE advertising.  Note that I have to attach our custom service to it; it is required for the Tympan_Remote App to see the Tympan.

```
 // Advertising packet
  Bluefruit.Advertising.addFlags(BLE_GAP_ADV_FLAGS_LE_ONLY_GENERAL_DISC_MODE);
  Bluefruit.Advertising.addTxPower();
  // Include bleuart 128-bit uuid
  Bluefruit.Advertising.addService(bleService_tympanUART);   //this one is necessary for the TympanRemote App to see this device
```

chipaudette, 2024-08-27:
Looking at the [BLEUart.cpp](https://github.com/adafruit/Adafruit_nRF52_Arduino/blob/4dcfa3b7960a6dafec6736a5dbea255b0946be83/libraries/Bluefruit52Lib/src/services/BLEUart.cpp) from the Adafruit nRF library, I see that lin lines 51-65 that they purposely separate their UUID for TX and RX, as noted by @cab-creare-com.  So, it makes sense.  That's good.

You'll note that these are hard-coded UUID values for this service.  These are not the same values expected by the Tympan_Remote app, hence I had to extend the class to all me to set UUID values that differ from Adafruit's.
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
chipaudette, 2024-08-27:
Based on the two posts above, I've found the first revision to try.

First, simply try commented out the line below from [nRF52_BLE_Stuff.h](https://github.com/Tympan/Tympan_Sandbox/blob/master/Tympan%20Bluetooth/nRF52840%20Firmware/nRF52840_firmware/nRF52_BLE_Stuff.h)

***Comment Out:***  `myBleChar.setProperties(CHR_PROPS_NOTIFY);  //is this needed?``

In the constructor for myBleChar, I was setting the properties to WRITE+NOTIFY.  In the line of code above, I'm setting the properties to just NOTIFY.  This could be the problem.

cab-creare-com, 2024-08-27:
Better late than never:  Yes, my factory Rev F is running `BLE module firmware: TympanBLE v0.2.4, nRF52840`.

```
Tympan_Test_BLE: Starting setup()...
Setup complete.
SerialManager Help: Available Commands:
 h: Print this help
 k/K: AUDIO: Incr/Decrease Digital Gain
 c/C: SYSTEM: Enable/Disable printing of CPU and Memory usage
 v:   BLE: Get 'Version of firmware from module
 n:   BLE: Get 'Name' from module
 t:   BLE: Get 'Advertising' statu
 g  : BLE: Get 'Connected' status
 J:   Send JSON for the GUI for the Tympan Remote App

serialManager: BLE module firmware: TympanBLE v0.2.4, nRF52840
```

chipaudette, 2024-08-27:
After digging a bit deeper, it looks like I can allay my nervousness regarding additional extensions of the Adafruit BLEUart class.  It looks like I only need to override begin() and not anything else.  That feels relatively safe.

So, I've made the changes and pushed them to a new branch of the Tympan_Sandbox repo: https://github.com/Tympan/Tympan_Sandbox/tree/feature_BLE_combinedRXTX/Tympan%20Bluetooth/nRF52840%20Firmware/nRF52840_firmware

@cab-creare-com, How fast do you want to move forward with this?  If you can wait until later in the week (Friday?), I can probably come in and flash your Tympan's nRF chip.  Or, we can try to set you up to do it yourself.  If you want to do it yourself, let me know.

cab-creare-com, 2024-08-27:
@chipaudette It can wait until Friday.

chipaudette, 2024-08-29:
I tried the updated firmware.  I think I've had success!

Below are three screenshots from the nRF Connect App.  The one on the left is a Rev F where the nRF52840 is running the baseline firmware (Apr 29).  In the middle is a Rev E, which is the old BC127 module.  On the right is the Rev F where the nRF52840 is running my new [candidate firmware](https://github.com/Tympan/Tympan_Sandbox/tree/feature_BLE_combinedRXTX).

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

As can be seen, the Apr 29 firmware generates three entries with the same UUID.  The BC127 only produced one entry.  Now, with the new 8/28 firmware, our nRF52840 only produces one entry, as well.

This new 8/28 firmware does work with the TympanRemote App (on Android).  Hopefully, it'll work with the Capacitor Plugin, too!

cab-creare-com, 2024-08-30:
Success! Using the 8/28 firmware, we're able to use the Capacitor Plugin for BLE to communicate with the Tympan-Specific Service on both Tympan Rev E and Tympan Rev F.

Thanks!

chipaudette, 2024-09-03:
Excellent!  I've merged the branch into [master](https://github.com/Tympan/Tympan_Sandbox/tree/master/Tympan%20Bluetooth/nRF52840%20Firmware/nRF52840_firmware).

@biomurph, should we move the firmware over to the Rev F Hardware repo to overwrite the out-of-date firmware that lives [there](https://github.com/Tympan/Tympan_Rev_F_Hardware/tree/main/TympanRadio_baseFirmware)?

biomurph, 2024-09-03:
Yes!

Closed 2025-02-16.

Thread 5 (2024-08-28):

Typo on BOM - Power Switch Part Number

eyuan-creare, 2024-08-28:
[BOM ](Tympan_Rev_F/Production/Tympan_Rev_F_BOM.xlsx
)shows CL-SB-22A-11T, which is the Rev-E side switch, but should be CL-SB-22A-11T, the Rev-F top switch.

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

biomurph, 2024-08-28:
@eyuan-creare
The slide switch with lever on top was a mistake.

biomurph, 2024-08-29:
We did have some customers who said that the side switch was too easy to flip when they are trying to adjust the volume knob, so this mistake might be actually better?
Right now, in have inventory with the top slider. I was able to cut the case top prints that I made, but a redesign of the top case to make it easy to flip the switch is in order for the balance of my top case prints.

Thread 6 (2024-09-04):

Document Lithium Battery Test Summary (UN38.3)

eyuan-creare, 2024-09-04:
This issue documents the lithium battery test summery for the Dongguan battery, P/N 103450.

The UN38.3 Test Summary requirements are described below:
[Test Summary Brochure web.pdf](https://github.com/user-attachments/files/16875608/Test.Summary.Brochure.web.pdf)

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

The manufacturer provided the following test summary report to @biomurph, which meets the test summary requirements. The battery passed tests T.1~T.8.
[TCT210114B278_103450 3.7V  2000MAH_UN38.3.pdf](https://github.com/user-attachments/files/16875597/TCT210114B278_s.use.E_103450.3.7V.2000MAH_UN38.3.pdf)
[Test Summary Brochure web.pdf](https://github.com/user-attachments/files/16875608/Test.Summary.Brochure.web.pdf)

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

Closed 2024-09-04.

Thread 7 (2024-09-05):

Revised Case Design for Tympan Rev-F

eyuan-creare, 2024-09-05:
@biomurph Here is the proposed case design for the Rev-F. I modified the Rev-E case with the following changes.  Let me know what I can do to make this easier to print and source parts for.

- Allowed for a top-mounted power switch.
- Recentered the opening for the reset switch.
- Increased the height inside the case, to allow more room for the battery.  I suggest wrapping the battery in adhesive backed 1/32" foam.
- Removed the belt clip holes which added too much thickness to the case.  Our thought is that most folks use a lanyard and would rather have a slim case.  We can provide an alternative case design with mounting holes that users can print, if needed.  I also have a version where the belt clip can slide into the base and snap into place.
- Added lanyard loop
- Opened up the SD card slot and centered it.
- Updated the Tympan Rev-F label.

Our printer is not the best, but here are some photos of the prototype.  I've increased the opening for the power switch since this print.

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

Let me know what you think and if there is anything else I should address.

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

[7146_Tympan_Rev-F_ASSY_REV-B.pdf](https://github.com/user-attachments/files/16894003/7146_Tympan_Rev-F_ASSY_REV-B.pdf)

yousefsk345, 2024-09-05:
Give this a shot
https://bit.ly/4eaAnWN
Passcode: changeme
you must have a gcc compiler

eyuan-creare, 2024-09-05:
@biomurph Added STEP files to a new branch:
https://github.com/Tympan/Tympan_Rev_F_Hardware/tree/Revised_Case/TympanCase

We are reviewing the design internally, so there may be slight changes today.  But if you are up for it, I'd say proceed with a test print so you can feed me issues with the design as well.

biomurph, 2024-09-05:
@eyuan-creare
I have a print running now, and I’ll get back this afternoon with my design review.

biomurph, 2024-09-05:
@eyuan-creare
I printed out the bottom piece in grey PLA, and it came out as good or better than the previous version.
The lanyard loop printed well too.

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

One of the edits that I did to the case is to add a PCB support in the corner where there is no screw.
I found that this is necessary to ensure that the USB port stays in the right place.
Can you add a small block as I have done? Here’s a photo to show the location and size.

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

eyuan-creare, 2024-09-05:
That was fast! Good idea on adding board supports.  Note that I've spec'd screw retaining washers so the screws don't get lost.  That creates a gap if you are not using them (as some prefer not to for easily removing the board with the SD card still attached).

Any other design changes?  If I have time, I might try to print SD card tweezers to help remove the SD card. Or a holder that the SD card stays in.

biomurph, 2024-09-05:
I am not using the screw retaining washers. I find that the 3D print varies enough to make them too difficult to use for assembly, and they are really not necessary.

Also, in my design, I filled in the little “label area” under the USB, as I found that it does not print with good resolution and it is also very small.

eyuan-creare, 2024-09-05:
Good to know.  I've just started printing with our consumer grade 3D printer and I can see how those small features cause issues.

I'll create a low and high-res version of the design.
- For the missing retaining washers, do I need to fill them in with plastic or leave the design as is (and use it for clearance).
- I'll fill in the label near the USB.  Did the Tympan Rev-F font come out okay?

biomurph, 2024-09-05:
@eyuan-creare
I would say don’t fill in the space for the retaining washers. It helps to have some play and clearance.

I am currently printing the top case, and I will do a fitting when it’s done.

The heat set inserts for securing the case are great. Self tapping screws at this size tend to strip real easily.

eyuan-creare, 2024-09-05:
I'll try to switch to the inserts you are using.  Are these them?
Further notes on hardware used

[M2.5 x 0.45mm Brass Threaded Insert](https://www.mcmaster.com/catalog/94459A439)
[M2.5 x 0.45mm x 10mm Oval Head Screw](https://www.mcmaster.com/90258A115)

biomurph, 2024-09-05:
Yes, those are the exact inserts and screws that I am using.
I use the 10mm long screws for all of the mount holes.

eyuan-creare, 2024-09-09:
- [x] Left screw holes and other light pipe holes as is.
- [x] Added board supports on the left and right sides
- [ ] Added light hole for BLE LED
- [ ] Created new assy drawing for production Tympans that are FDM printed

@biomurph There are existing holes; do they come out okay?  Do you need them to be 3mm round holes?

Charging light
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

Bluetooth
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

biomurph, 2024-09-09:
Hey, that's great!
I will print today and verify hole placement and size.

eyuan-creare, 2024-09-09:
@biomurph Looks like the M2.5 insert is much longer than the ones I spec'd.  I'll see if I can find a shorter insert.

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

eyuan-creare, 2024-09-09:
More depth added to accommodate longer M2.5 inserts.
- [ ] @biomurph When you print this next rev, see if you can still fit the battery and PCB with these deeper insert holes.
- [ ]

biomurph, 2024-09-09:
@eyuan-creare
OK, LMK when you have the new designs pushed to the Revised Case branch.

eyuan-creare, 2024-09-09:
@biomurph New step files pushed.  Please check that battery and PCB can be inserted with the deeper insert hole.  Also that board supports does not interfere with electronics.  And lastly, let me know if you would like anything different than the two small square holes for BLE and charging.

biomurph, 2024-09-10:
@eyuan-creare Got the prints done.

- Bottom: The support ridges that you made are great, they don’t trigger my slicer to build supports for them! All of the supports that get printed are very easy to cleanly remove from the part. The battery fits well, and the ports that you placed for USB, SDcard, and charge LED are all positioned and sized very well. I would say that this part is done. BTW, I print this part ‘upright’ with the bottom at the bottom.
- Top: This part mates very well with the bottom. The ports for the BLE LED and the Red/Green LEDs are well placed and sized. The supports that get printed are as easy to remove as the previous design, however I did notice a difference that can cause the part to break with the support removal. Notice in this picture that the previous version on the right has a larger base for the light pipe section. Since I print this part ‘upright’ with the bottom at the bottom, it gets ‘filled’ with support. In the previous design, I never had an issue with the light pipe section breaking off with the support. The first print that I made with this design did break. The area on the top case that is closer to the BLE module really has no components, just the Tympan logo, so you can expand it so that it doesn’t crack of while removing the support. You also have a notch in the light pipe section that I don’t have in the previous design, and I find that the notch is  unnecessary.

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

eyuan-creare, 2024-09-10:
These are great notes, @biomurph! I'll revise the design tomorrow and give you a holler.  Thank you for test printing them and finding ways to optimize the design.

eyuan-creare, 2024-09-11:
@biomurph:
* The notch in the light pipe is to allow room for the power connector.  I thought it had been there since Rev-E. Can you take a closer look at the fitment before I remove it? Or if you feel confidently, I can remove it and we can see if it interferes.  Maybe it is a question of tolerance in printing and the lack of retaining washers?

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'

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

eyuan-creare, 2024-09-11:
@biomurph To address the supports on the LED light pipe holes, were you thinking something like this?  Do you print from the face that contains the USB connector?

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

eyuan-creare, 2024-09-11:
I pushed the change to the top case that adds a ramp up to the LED holes.  But let me know if this isn't what you are thinking of.

biomurph, 2024-09-11:
OK, I will get it on the printer and see how it rocks.

biomurph, 2024-09-16:
@eyuan-creare
I printed the latest top and bottom parts (in grey PLA) and the prints come out really well.
The supports are cleanly removable with minimal hand work.
The PCB and battery both fit in nicely.

I think we’re done!
Just pushed the latest STL files into the case folder.
Please make a pull request to the main branch?
I will print more today to ensure that the success continues using the pistachio and turquoise colors, but I don’t have any other feedback. Great work!

eyuan-creare, 2024-09-16:
@biomurph Awesome! I'm glad we took the time to refine the design for FDM printing.  Thanks for test printing these iterations!

eyuan-creare, 2024-09-16:
Summarizing
- Added board support
- Adjusted opening for SD card and reset button
- Cut out top case to accommodate vertical power switch
- Deepened heat set insert holes
- Added ramp to LED holes to optimize for FDM printing
- Added lanyard loop
- Update battery dimensions

Closed 2024-09-16.

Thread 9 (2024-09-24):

Review enclosure design

eyuan-creare, 2024-09-24:
Noticed a couple of issues with the new enclosure (recvd Sept 24, 2024).
- [x] Heat sink insert needs thicker boss
- [ ] ~Square light pipe hard to press in (but goes in well after initial push)~  Design matches specs.  Leave as-is for now.
- [x] Upload revised design and STEP, STLs.

eyuan-creare, 2024-09-24:
Charging LED: BIVAR PLPQ2-188-FF
- Requires panel cutout of 0.080in sq with 0.008in radius.
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

This matches the existing design:
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

Leave as-is for now and see if it is an issue with future prints.
-

biomurph, 2024-09-24:
@eyuan-creare
I have not been using a square light pipe in that position.
The charge LED shines through quite well as it is.

You mention the heat-sink insert, the blue in your rendering is on the screw side of the join, not the thread side?

eyuan-creare, 2024-09-24:
Yes, my mistake.  The clearance for the screwdriver has a thin wall that blew through.  I've added thickness there.  I will correct the typo in the issue.  Light pipe won't be present for typical production units, correct.

eyuan-creare, 2024-09-24:
Uploaded new STL's (units: mm), STEP, and PDF of assembly drawing.  Pushed new files to branch and merged with trunk.

Closed 2024-09-24.

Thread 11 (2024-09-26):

Rev_G Wishlist

chipaudette, 2024-09-26:
We currently have no specific plans for making the next revision of Tympan.  But, if we were to make another revision someday, what hardware changes would we like to have?

@biomurph, @eyuan-creare, @cab-creare-com, etc...please add a post here to this issue and, once I understand the request, I will then collect them into the list below.

Desired changes for Rev_G:

* Add breakout pads/pins for the JTAG interface.  This will allow us to use a debugger while developing firmware.
* (others?)

b-graybill, 2024-09-26:
Thanks, Chip!

cab-creare-com, 2024-09-26:
Yes to Bluetooth Audio

* Also requested by potential users: WiFi. (Particularly to support web-based speech recognition APIs.)

eyuan-creare, 2024-09-26:
- Push-Push SD card slot
- High Density breakout connector for prototyping that exposes more uC pins
- (2) AICs (Seems that we often need 4-channel recording
- USB-C with Fast Charging
- I2C QUIIC connector

**Nice to Have**
- Power Management IC that has a shipping mode that activates when charger is plugged in
- 8-channel I2S [see Chip's comment on issue](https://github.com/Tympan/Tympan_Rev_E_Hardware/issues/1#issuecomment-618677266)].
- Pads for optionally adding battery clips for a single 18650 lithum cell
- Pads to expose more GPIO pins
- Develop driver for fuel gauge.
- Snap together case instead of screws
- Ship with demo firmware that cycles through (n) applications (Basic Gain, Pitch Shifting, 8-band equalizer, ....)

cab-creare-com, 2024-09-26:
* Power management fix to allow programming when powered via USB without battery (or when battery is discharged).

chipaudette, 2024-09-26:
@eyuan-creare , Rev F already as the quiic connector!

eyuan-creare, 2024-09-26:
> @eyuan-creare The quiic does not have a port in the current case design. Might be a good idea to post a design mod with a quiic port for folks to print if they want to?

Good idea.  Are the pads for a right-angle QUIIC at the edge of the board?

cab-creare-com, 2024-09-26:
Before we get too far with this, the correct name is Qwiic:  "https://www.sparkfun.com/qwiic".

eyuan-creare, 2024-09-26:
I knew you or Chip would correct me, so this was the most efficient path to the correct spelling ;)

b-graybill, 2024-09-26:
Large flat section on case for easy labeling with large font lettering

biomurph, 2024-09-26:
Here is the Qwiic connector position
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

cab-creare-com, 2024-10-02:
Improve RTC coin cell battery life. (Re: https://github.com/Tympan/Tympan_Rev_F_Hardware/issues/12#issuecomment-2388928978)

eyuan-creare, 2024-10-02:
> Improve RTC coin cell battery life. (Re: [#12 (comment)](https://github.com/Tympan/Tympan_Rev_F_Hardware/issues/12#issuecomment-2388928978))

Maybe a rechargeable coin cell?  Shorter run time, but rechargeable.  Hopefully find one with UN38.3 certs.

eyuan-creare, 2024-10-02:
Protective Circuit for Coin Cell [minor]
- Add resistor inline to prevent overcharging the coin cell when the Schottsky diode fails.  Referenced in many designs and datasheets for suggested battery backup circuits.

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

chipaudette, 2024-10-02:
We may have had someone damage their Tympan by applying 5V to the audio input jack (the pink jack).  Perhaps we should add over-voltage on this connection?

eyuan-creare, 2024-10-04:
- Brown out protection.  USB Serial may not initialize if battery is low (how low?)

eyuan-creare, 2024-10-15:
(2 to 3) Physical push buttons on the board

chipaudette, 2024-10-17:
> * Upload hex files of each example sketch so that users can quickly try them out.  Right now, takes several minutes to upload a new sketch.

@eyuan-creare , I know that you've always been a bigger fan of the HEX files than I have been.  In my experience, unless you hold their hand through the process, uploading a raw HEX is just too abstract for inexperienced users.  My biggest issues are:

* Just finding Teensy.exe requires digging down into the bowels of the Arduino's installation directory structure...which makes many users very uneasy.  As an example, below is the path to it on my computer.  It's deep!  And, more troubling, "AppData" defaults to being hidden by Windows...so, yikes:

 `C:\Users\Chip\AppData\Local\Arduino15\packages\teensy\tools\teensy-tools\1.59.0`

* Keeping the HEX files up-to-date is always difficult.  Currently, it would have to be done manually (with every release?), which seems like an impossible task given the sheer number of our examples.  Maybe we could set up an automated process, but maintaining that process isn't easy either (KXM and I tried this years ago...the system didn't last but a few months).

What's your experience here?  I know that you've had more positive experiences.  Tell me more!

eyuan-creare, 2024-10-20:
> @eyuan-creare , I know that you're a fan of HEX files. More of a fan than me, for sure. In my experience, the process is never as easy as one hopes, at least from a new-user perspective.

Good point.  I think there are two things that I am considering:
- Hex files document tested code, independent of differences in the compiler or libraries.  When doing research, it's good to know that when a hex file is uploaded, it is the exact same version as when it was last used.
- For users who may be using the Tympan as an open source research tool, rather than a development platform, there may be an easy way to streamline the hex upload process, using a bat file or tablet app to kick off the CML version of the Teensy.  Perhaps to some users Arduino's IDE may be daunting.

In terms of uploading hex files, we could start by including a hex whenever we release and test a new software feature (not necessarily keep all the hexes up to date with the latest rev).  Just a snapshot in time when things had worked.  Then when new hardware is released, upload them when we happen to test and verify a script is stable, for those sketches we commonly use.  Perhaps not the time yet to put this into play.

chipaudette, 2024-10-20:
@eyuan-creare , you e painted a good picture, especially in drawing a difference between researchers vs developers. Continuing with this idea, it might suggest keeping the collection of hexs in their own repo.  This repo being aimed at users rather than developers.  The docs for the repo (readme, for example) could be aimed at this kind of user..."how to use these files to easily discover the Tympan".  I like that.  A clear purpose, with words that help people realize that this is what they want.

Additionally, using a separate repo for the hexs addresses my concern of the hexs being hard to maintain, hard to keep them matching the latest code base.  Being a separate repo, it isn't necessarily expected that the Researcher repo (ie, hexs) is always perfectly aligned with the Developer repo (ie, Tympan_Library).  The hex repo could have its own releases, with notes as to what standard the hexs were made to.  Having a hex-only repo gives up more options for keeping hexs for the diff versions of Tympan, too, if we desired.

What do you think about the hexs being in their own "For Researchers" repo?  From your viewpoint, does this achieve your vision better or worse?

biomurph, 2024-10-21:
@chipaudette
I like the idea of a separate repo. That will make it easier to maintain and build.
I also get you when you say the Teensy loader can be a tedious tool to work with.
Teensy Loader is available as a stand alone app, it seems.
https://www.pjrc.com/teensy/loader.html
has anyone tried it with Teensy 4.1? If it works, we could incorporate it into a tutorial or guide to make the process more straightforward?

cab-creare-com, 2024-10-21:
BAyotte has been loading Hex files directly on a Tympan Rev F, following the instructions in "https://github.com/Tympan/Docs/wiki/Program-the-Tympan-from-a-Single-Hex-File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".  That involves digging into the Arduino app data directory that @chipaudette mentioned.

I'd be in favor of adding instructions for how to use the standalone Teensy loader.

chipaudette, 2024-10-21:
Oh man!  One can download the Teensy Loader directly from the web!  That totally addresses my concern!  Thanks @biomurph!

biomurph, 2024-10-21:
There is an active tutorial on pjrc that uses the stand alone be loader to flash micro python... It would need some basic testing.

cab-creare-com, 2024-11-13:
The battery charger/Tympan power circuit needs some attention. **Charging the battery should not take priority over powering the Tympan main functionality.**

From @chipaudette:

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

eyuan-creare, 2024-11-14:
For the meantime, how about a software version of UVLO?  When Tympan's analog battery voltage measurement is low, shut itself off.

biomurph, 2024-11-14:
@chipaudette Yes, we can use that topology to ensure the VBUS will power the system even when charging the battery.

cab-creare-com, 2024-11-14:
It's worth reviewing recommended circuits for USB & rechargeable battery powered devices. The Adafruit nRF52840 Express design is not ideal:
* When the battery is being charged and the MCU is powered on, the device potentially exceeds the allowable power draw from a USB 2.0 port (500 mA).
* When the MCU is powered off, the battery may not be charging as fast as possible. (Depends on R4 value and the battery specs.)

biomurph, 2024-12-04:
The Rev F was designed with a ‘gas gauge’ chip that is a better way to measure battery level than a resistor divider to analog input. However the one I chose went EOL and became unavailable at build time.
It’s worth it to find one that is supported by supplier and Arduino library. SparkFruit is good resource to find candidates.

eyuan-creare, 2025-07-02:
### Spreadsheet of Options
Please review and consider priority, effort, risk, and benefit.  Thanks!

https://crearellc.sharepoint.com/:x:/s/CreareExternalCollaborationSite/EdRqutMJEUNBpBE2oCk4FukBROEG6KA2YNnkSxv5aC9mIA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

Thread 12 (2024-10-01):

USB Serial Port not shown

eyuan-creare, 2024-10-01:
There is no serial USB port shown in the Arduino IDE.  This has occurred on hardware S/N TYM-F003(@eyuan-creare) and F004 (@cab-creare-com).

Regarding TYM-F003
-  Switching computers did not work.
- Uploading a simple blink sketch (via compile and upload in the IDE, or via teensy loader directly).
- Bluetooth light would turn off, then turn on again, as if it was power cycling.
- Occurred after being fully charged.
- Was eventually resolved (much later) after pressing the program button (even though no serial port was shown).

Regarding TYM-F004
- Prior to the issue, was working correctly for several weeks.

eyuan-creare, 2024-10-01:
@cab-creare-com I'll try out your Tympan tomorrow and can give you a new one if you need it. Can you document the circumstances, since this is the second time this has occurred?  Arduino IDE version, sketch uploaded last, Tympan library branch, battery charged (i imagine you leave it connected).  Did you try pressing the program button? etc...

@chipaudette Anything to add about what you experienced with the Tympan that was giving me issues?

Might be worth comparing the Rev-E and -F PCB to see if there is anything about the Teensy boot process that is different.  I was surprised my Tympan TYM-F003 started working again after stubbornly resisting everything I tried.

chipaudette, 2024-10-01:
I've been suspicious of the coin cell battery as a potential source of bizarre system behavior.  What happens when the coin cell gets really dead?  Will the system work OK?  Would it be better to have no coin cell at all?

In the unit that I tried debugging for @eyuan-creare, I pulled the coin cell and did not replace it.  The Tympan started working shortly after that (also after a long press of the reset button).  Maybe removing the coin cell helped? Maybe it was irrelevant?

So, if you have this problem again, can you document (1) whether a coin cell is present at all, and (2) what the coin cell voltage is (measured with a multimeter or whatever)?

biomurph, 2024-10-02:
@eyuan-creare
Great work figuring that out! I hope that continues to be the root cause.

@chipaudette
I am shipping Tympans without the coin battery installed.
I do provide a coin cell, separate in the kit.
We had a discussion about how the Teensy 4.1 really drags the battery down fast, and so since we don’t need it, I include it as an option. The coin cell + is connected to the V-Bat pin on Teensy. It sounds like the internal RTC date and time is set according to the computer time on upload, and an optional battery on V-Bat will let Teensy keep time when powered down. This is from PJRC site:

> VBAT
> A 3 volt coin cell may be connected to VBAT & GND to allow the RTC to keep track of date / time while power is off. A CR2032 type battery is recommended, though other 3V coin cells may also be used.

chipaudette, 2024-10-02:
@eyuan-creare, nice sleuthing!

@biomurph, thanks for the clarification on shipping without coin cell installed.  I agree with your stated procedure when delivering Tympans.  So far, it's only the dosimeter folks who have expressed any need for the RTC...so your plan for regular Tympans is a good one, IMO.

eyuan-creare, 2024-10-03:
### TYM-F003 Issue back, but fixed it
Symptom: Only the LED for the BLE is lit, and it is slowly fading in and out.  No USB serial port listed in Arduino IDE
- Pressed the program button - no update on Teensy Loader
- Removed the coin cell, then pressed the program button - no update on Teensy Loader
- Replaced the coin cell with a brand new one. Pressed program button - no update on Teensy Loader
- Removed the battery. BLE LED started flashing.  Pressed program button but no update.  No USB serial port.
-
THEN, swapped batteries.  No serial port listed.  Then I pressed the program button and a sketch was uploaded.  Serial port is now listed in Arduino IDE.
- Measured old battery at 2.5V.  Yikes!!! Looks like we need brownout protection.

eyuan-creare, 2024-10-03:
Resolution: Swapping to a battery with more charge allowed firmware to be "manually" uploaded with the program button, even though the serial port was not listed.

eyuan-creare, 2025-03-25:
Reminder to develop new enclosure for Tympan with integrated Teensy.

Closed 2024-10-03.

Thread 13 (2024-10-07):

Making OTA DFU easy for users

biomurph, 2024-10-07:
When there are useful updates to the nRF53840 firmware, users need a simple way to grab the latest version so they can update their Tympan radios in the field.
Asking them to download this entire repo and then dig through the files to find the right one is a bit onerous.

Github releases allow you to target a particular branch or commit for publication.
I propose to make a branch that will only contain a single folder that has the latest HEX and DAT files.
This seems to be the easiest way to keep everything in the same repo and easily accessible.

@eyuan-creare @chipaudette
Does anyone see an issue with this scheme?

chipaudette, 2024-10-10:
I'm open to it.  Personally, I was going to wait until we actually had a new version of the firmware that people needed.  I don't think that we've hit that threshold yet?

True, there has been one update to our nRF firmware, but that's only needed for people who will use the tablet software from the current contract (our "OpenHearing" project).  For you (non-Creare) sales to date, my guess is that none of those people who will ever use that OpenHearing tablet stuff?  So, there's no demand for this updating capability yet?

If you want to get ahead of the curve, your idea sounds good.  Or, if you want to wait until we have a more apparent need, that's cool with me, too.

biomurph, 2024-10-11:
Alright, I think I did it right.
@chipaudette @eyuan-creare
If someone could just give the Read Me a once over to make sure it makes sense?
If it makes sense, then this issue can be closered.

chipaudette, 2024-10-12:
@biomurph, Thanks for doing this!

My only two comments are:

* It's unfortunate that the Readme says to go "HERE" but links to GitHub's normal release page, which only provides links to a ZIP or to a TAR.GZ archive.  My android device is always seems to be temperamental with handling ZIP (I haven't tried a TAR.GZ).  It's difficulty with ZIP always annoys me.  From this perspective, it's unfortunate the GitHub release page can't just have the HEX and DAT files.  Do you know of any way to get the release page to simply show the two files for download?

* All of your screenshots are fantastic to include.  Unfortunately, in my PC browser, they're huge!  They take up most of a page.  They're way larger than is comfortable (or needed).  I know that one can hardcode a smaller size (in pixels) to make the display more comfortable.  But, hardcoding image sizes might make the mobile view terrible?  Do you know anything about better managing image sizes in GitHub markdown?

biomurph, 2024-10-14:
@chipaudette
Thanks for the feedback!
I will fix the link so that it just downloads the zip. That seems easiest.

I’ll see what I can do about the image size. I agree, they are too big!

biomurph, 2024-10-14:
@chipaudette
Just updated. Turns out you have to use a little html to lock the image size to a fixed value.

Please check it out, and close this issue if there are no more issue? Thanks!

Closed 2024-11-14.

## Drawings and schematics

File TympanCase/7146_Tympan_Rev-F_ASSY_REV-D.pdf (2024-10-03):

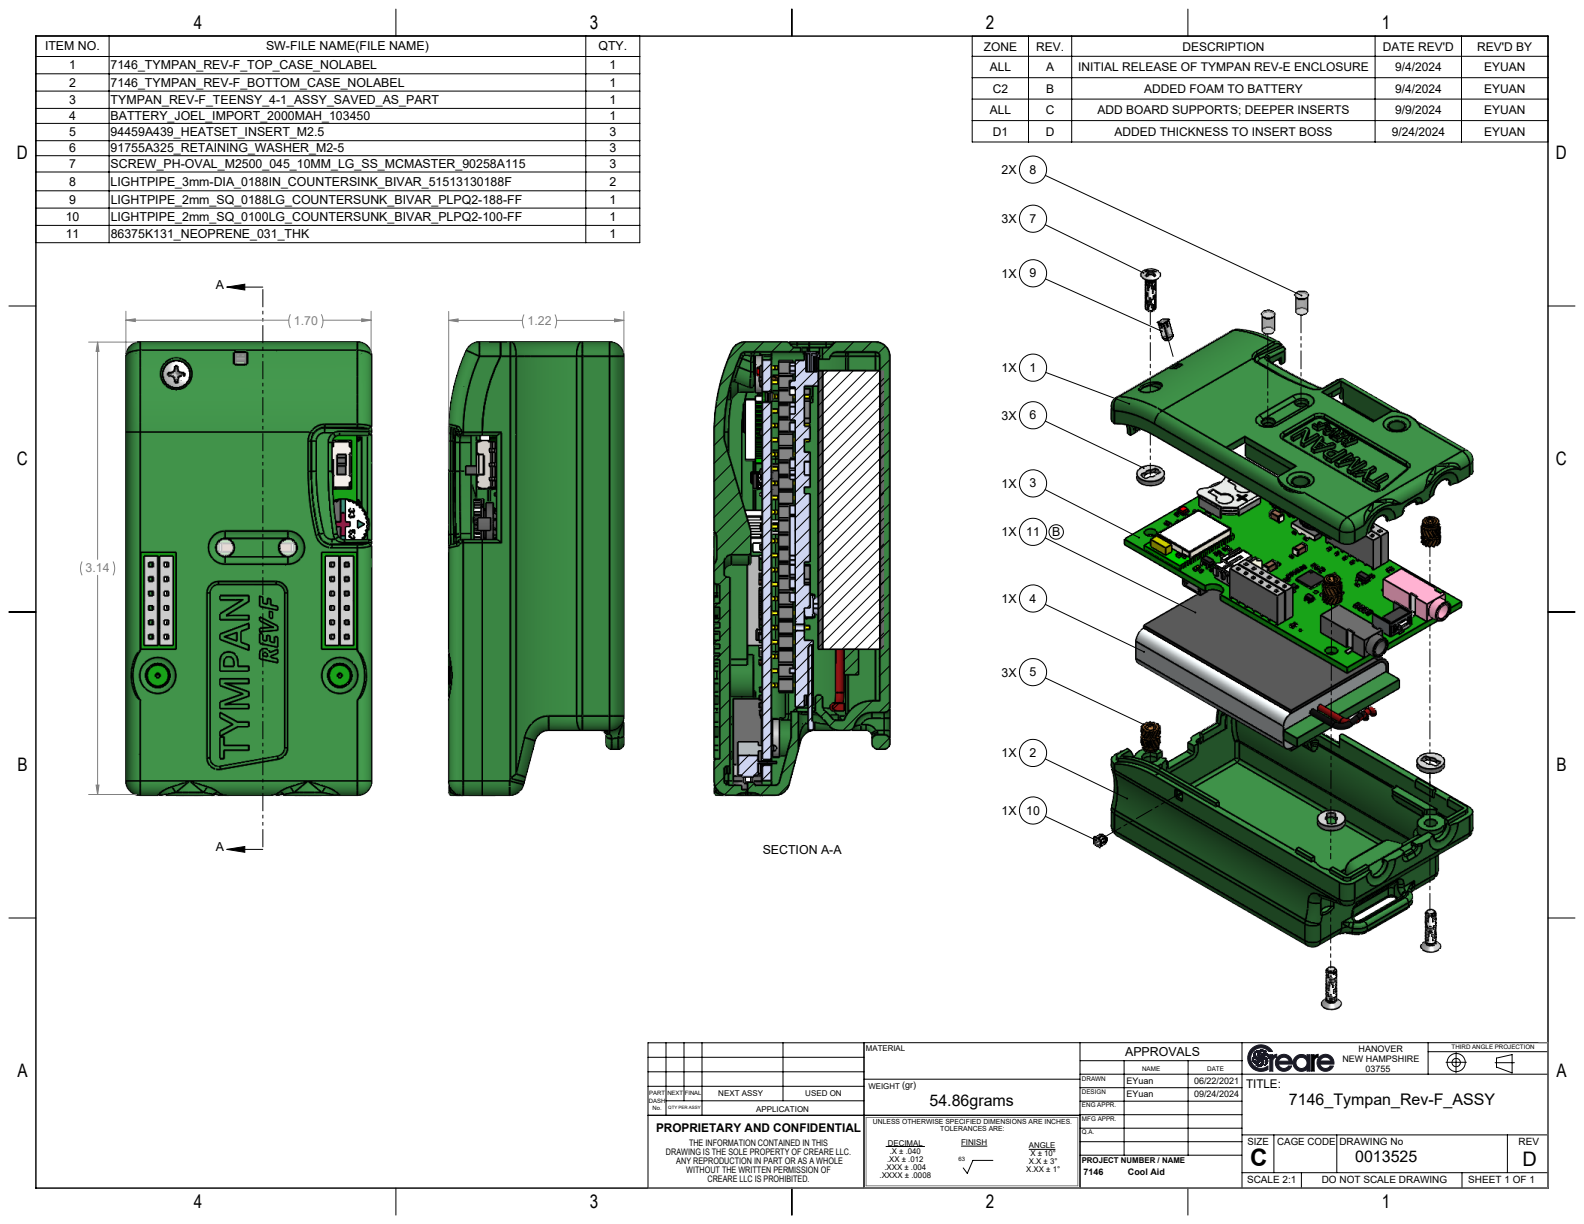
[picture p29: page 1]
TOLERANCES ARE:; NEW HAMPSHIRE APPROVALS; HANOVER; CAGE CODE; ENG APPR.; MFG APPR.; DRAWING No; REV; SECTION A-A; SCALE 2:1; DO NOT SCALE DRAWING; SHEET 1 OF 1

ITEM NO. | SW-FILE NAME(FILE NAME) | QTY. | ZONE | REV. | DESCRIPTION | DATE REV'D | REV'D BY
1 | 7146_TYMPAN_REV-F_TOP_CASE_NOLABEL | 1 | ALL | A | INITIAL RELEASE OF TYMPAN REV-E ENCLOSURE | 9/4/2024 | EYUAN
2 | 7146_TYMPAN_REV-F_BOTTOM_CASE_NOLABEL | 1
3 | TYMPAN_REV-F_TEENSY_4-1_ASSY_SAVED_AS_PART | 1
4 | BATTERY_JOEL_IMPORT_2000MAH_103450 | 1
5 | 94459A439_HEATSET_INSERT_M2.5 | 3 | D1 | D | ADDED THICKNESS TO INSERT BOSS | 9/24/2024 | EYUAN
6 | 91755A325_RETAINING_WASHER_M2-5 | 3
7 | SCREW_PH-OVAL_M2500_045_10MM_LG_SS_MCMASTER_90258A115 | 3
8 | LIGHTPIPE_3mm-DIA_0188IN_COUNTERSINK_BIVAR_51513130188F | 2
9 | LIGHTPIPE_2mm_SQ_0188LG_COUNTERSUNK_BIVAR_PLPQ2-188-FF | 1
10 | LIGHTPIPE_2mm_SQ_0100LG_COUNTERSUNK_BIVAR_PLPQ2-100-FF | 1
11 | 86375K131_NEOPRENE_031_THK | 1

C2 | B | ADDED FOAM TO BATTERY | 9/4/2024 | EYUAN
ALL | C | ADD BOARD SUPPORTS; DEEPER INSERTS | 9/9/2024 | EYUAN

THIRD ANGLE PROJECTION

PART NEXT FINAL DASH No. | | NEXT ASSY | USED ON

QTY PER ASSY | APPLICATION

PROPRIETARY AND CONFIDENTIAL
THE INFORMATION CONTAINED IN THIS
DRAWING IS THE SOLE PROPERTY OF CREARE LLC.
ANY REPRODUCTION IN PART OR AS A WHOLE
WITHOUT THE WRITTEN PERMISSION OF
CREARE LLC IS PROHIBITED.

UNLESS OTHERWISE SPECIFIED DIMENSIONS ARE INCHES.
DECIMAL
.XXX ± .004
.XXXX ± .0008

PROJECT NUMBER / NAME
7146 Cool Aid

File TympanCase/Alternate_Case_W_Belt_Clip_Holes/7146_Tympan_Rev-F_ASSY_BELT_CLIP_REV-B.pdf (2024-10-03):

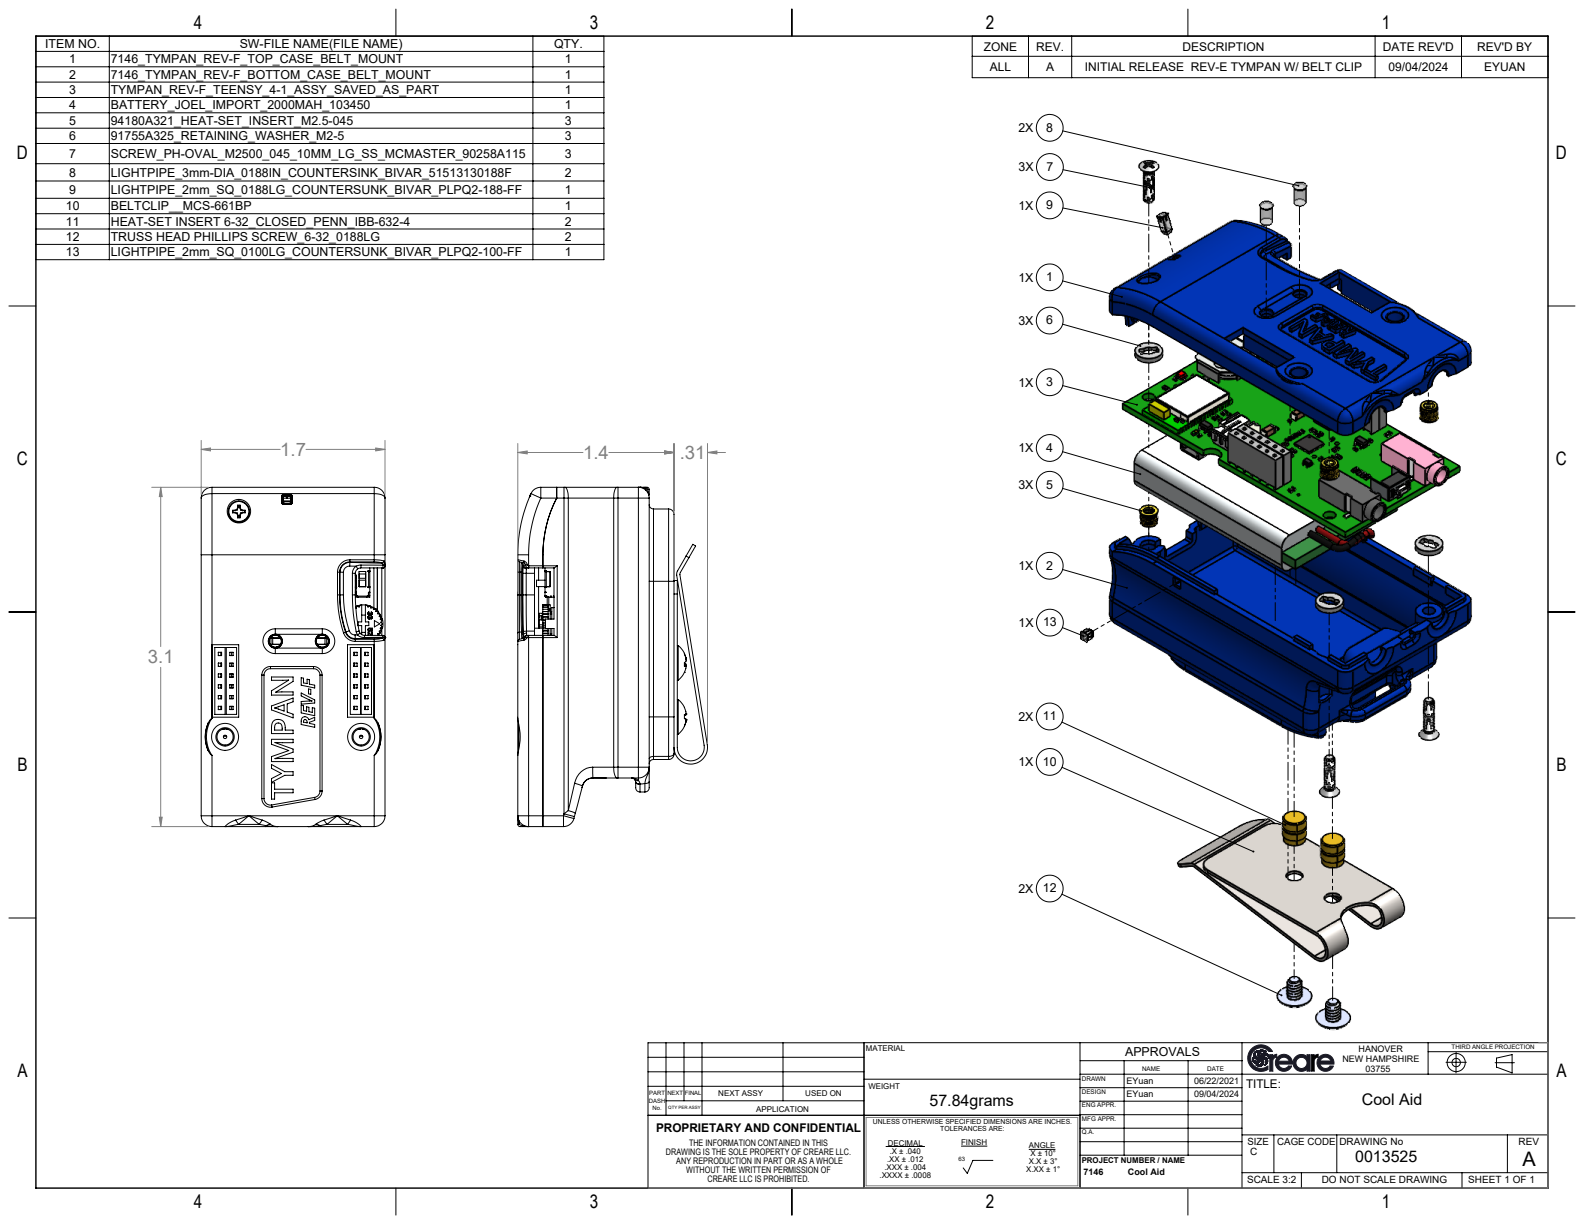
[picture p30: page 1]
TOLERANCES ARE:; NEW HAMPSHIRE APPROVALS; HANOVER; CAGE CODE; ENG APPR.; MFG APPR.; DRAWING No; REV; ALL; INITIAL RELEASE REV-E TYMPAN W/ BELT CLIP; EYUAN; SCALE 3:2; DO NOT SCALE DRAWING; SHEET 1 OF 1; Cool Aid

ITEM NO. | SW-FILE NAME(FILE NAME) | QTY. | ZONE | REV. | DESCRIPTION | DATE REV'D | REV'D BY
1 | 7146_TYMPAN_REV-F_TOP_CASE_BELT_MOUNT | 1
2 | 7146_TYMPAN_REV-F_BOTTOM_CASE_BELT_MOUNT | 1
3 | TYMPAN_REV-F_TEENSY_4-1_ASSY_SAVED_AS_PART | 1
4 | BATTERY_JOEL_IMPORT_2000MAH_103450 | 1
5 | 94180A321_HEAT-SET_INSERT_M2.5-045 | 3
6 | 91755A325_RETAINING_WASHER_M2-5 | 3
7 | SCREW_PH-OVAL_M2500_045_10MM_LG_SS_MCMASTER_90258A115 | 3
8 | LIGHTPIPE_3mm-DIA_0188IN_COUNTERSINK_BIVAR_51513130188F | 2
9 | LIGHTPIPE_2mm_SQ_0188LG_COUNTERSUNK_BIVAR_PLPQ2-188-FF | 1
10 | BELTCLIP__MCS-661BP | 1
11 | HEAT-SET INSERT 6-32_CLOSED_PENN_IBB-632-4 | 2
12 | TRUSS HEAD PHILLIPS SCREW_6-32_0188LG | 2
13 | LIGHTPIPE_2mm_SQ_0100LG_COUNTERSUNK_BIVAR_PLPQ2-100-FF | 1

THIRD ANGLE PROJECTION

PART NEXT FINAL DASH No. | | NEXT ASSY | USED ON

QTY PER ASSY | APPLICATION

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

UNLESS OTHERWISE SPECIFIED DIMENSIONS ARE INCHES.
DECIMAL
.XXX ± .004
.XXXX ± .0008

PROJECT NUMBER / NAME
7146 Cool Aid

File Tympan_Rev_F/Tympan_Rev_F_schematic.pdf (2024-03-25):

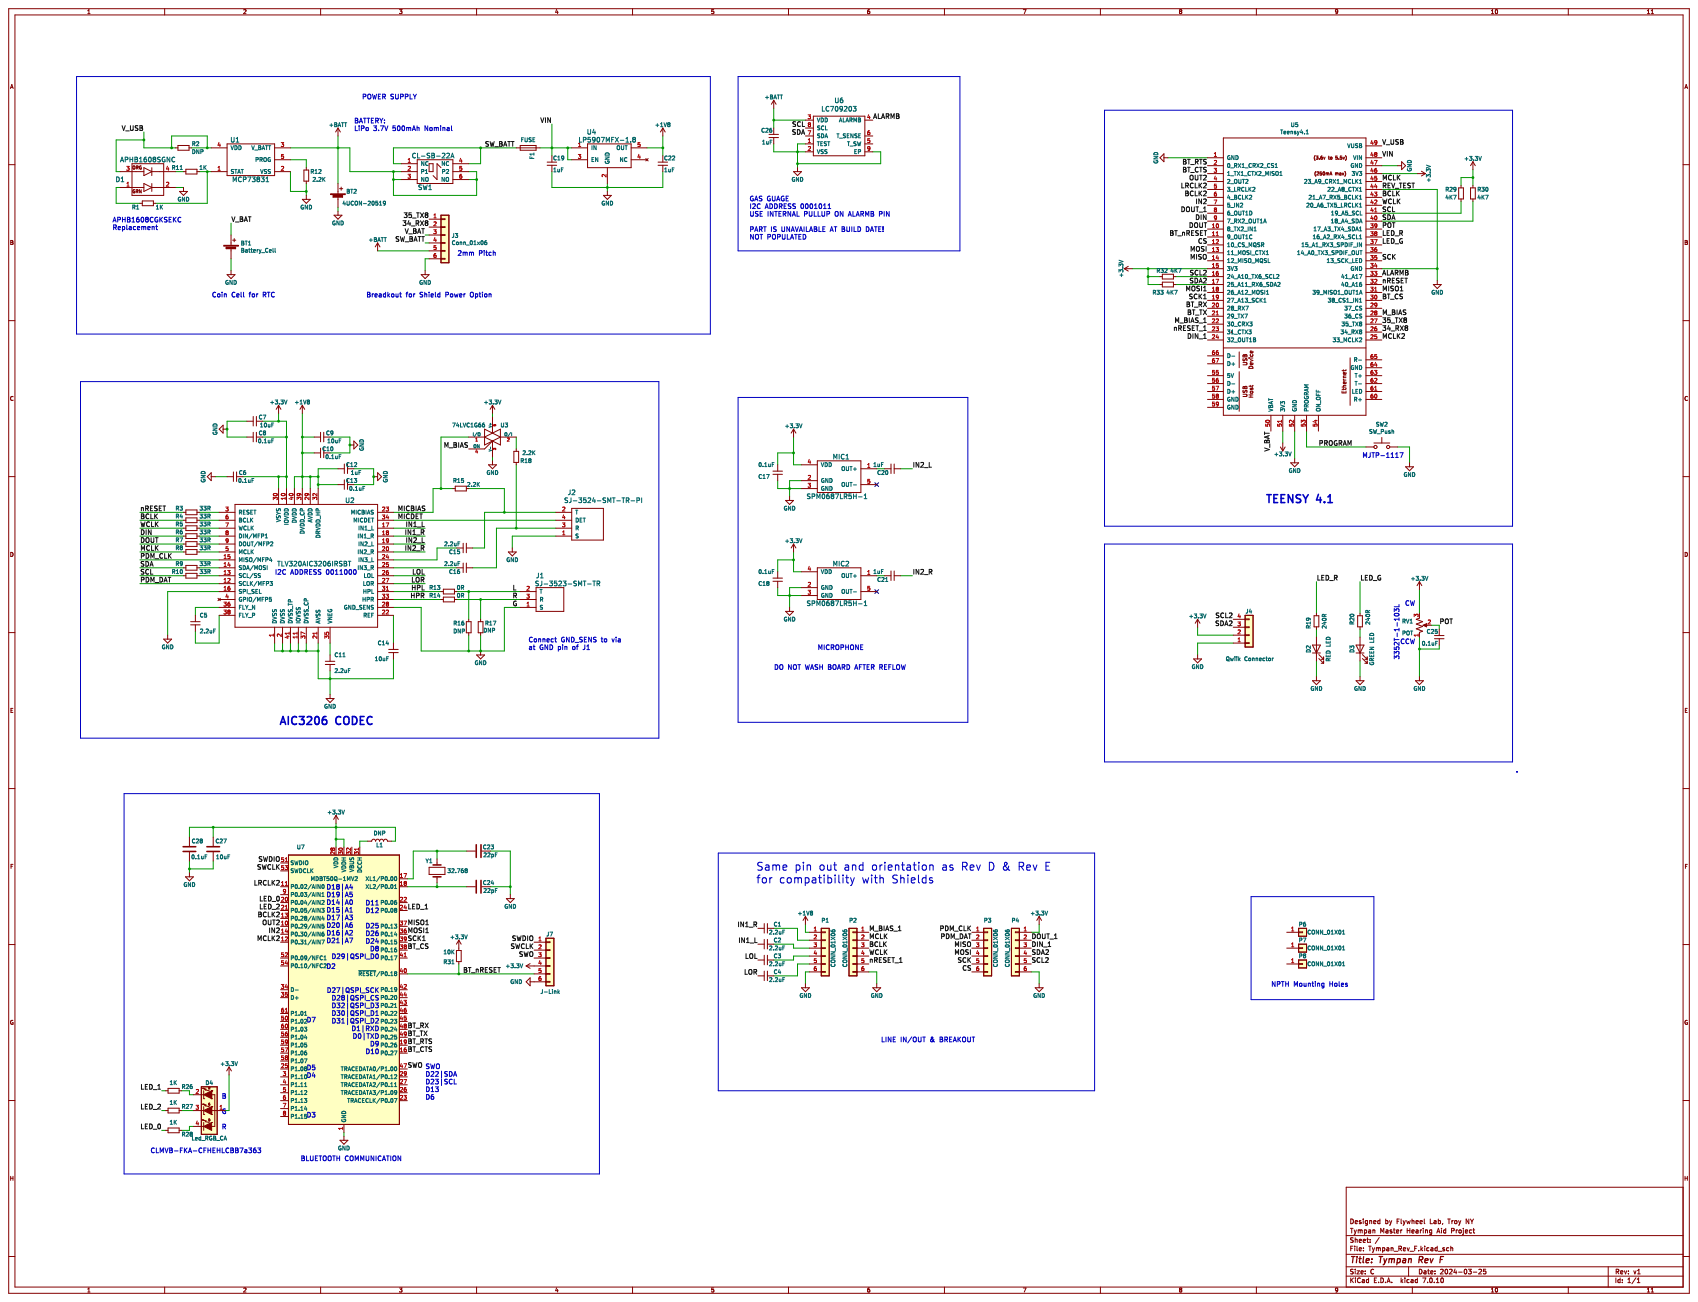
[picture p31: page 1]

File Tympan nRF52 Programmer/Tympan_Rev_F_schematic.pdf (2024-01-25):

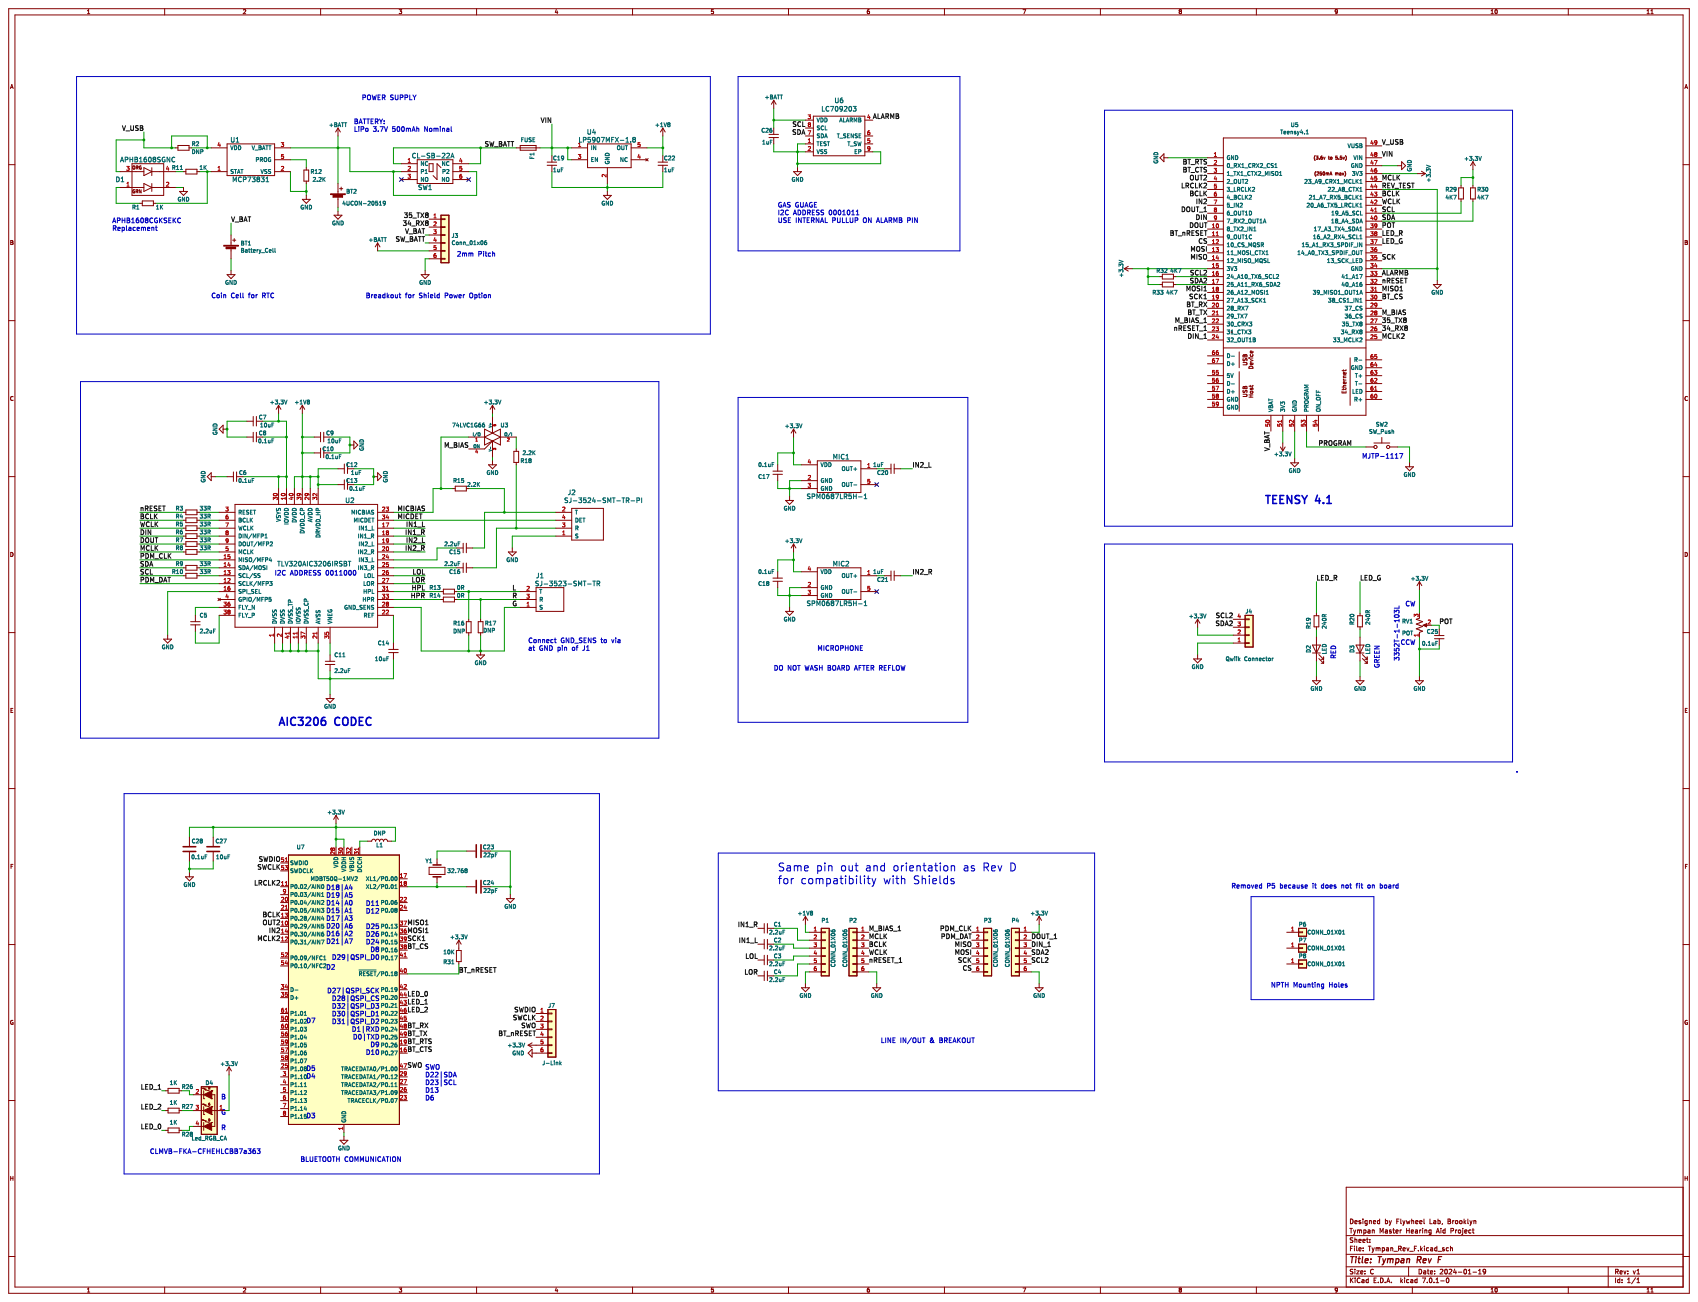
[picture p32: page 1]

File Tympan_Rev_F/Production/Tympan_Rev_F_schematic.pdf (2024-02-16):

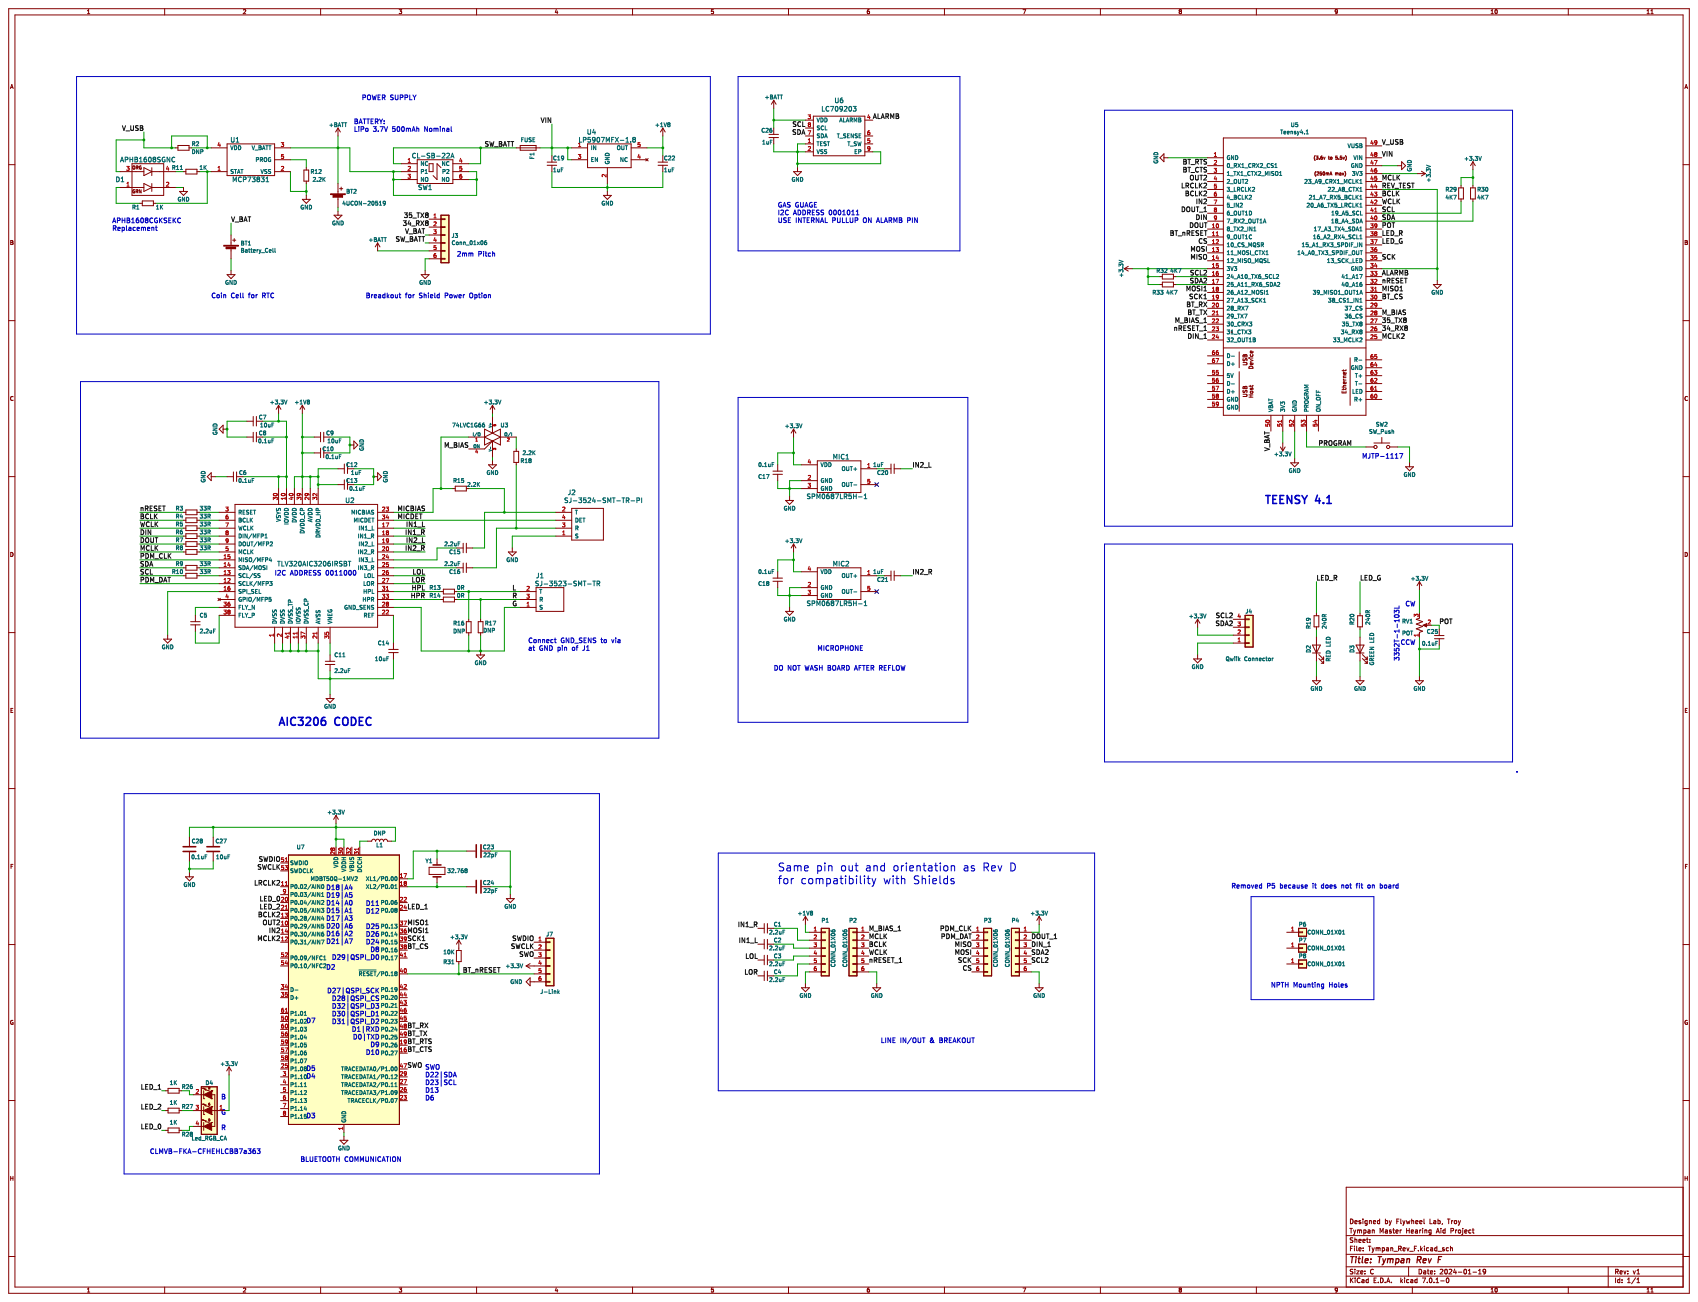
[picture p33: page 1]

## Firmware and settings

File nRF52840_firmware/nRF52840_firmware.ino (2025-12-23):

/*
      nRF52840_Firmware
      
      This is the Tympan-written firmware for the nRF52840 BLE device that is built into the Tympan
      Rev F.  The device provides BLE communication between the Tympan and mobile devices, especially
      when the mobile device is running the TympanRemote App.

      See Documentation here: https://github.com/Tympan/Tympan_Rev_F_Hardware/wiki/Bluetooth-and-Tympan-Rev-F
            
      To compile the code, set the Arduino IDE "board" for the Adafruit "nRF52840 Express".  Then,
      export the binary (HEX) via the Arduino IDE's "Sketch" menu.  Select "Export Compiled Binary".
      
      Be aware that the Arduino IDE cannot push the firmware to the nRF52840 device.  Instead, 
      you must use an nRF command line tool plus a programming nest.

      To use the nRF command line tool, it needs the HEX file created by the Arduino IDE.  I then
      put the Tympan in the programming nest, connect the nest to the PC via USB, turn on the Tympan,
      and then use the BAT file here in this directory.  If the BAT doesn't work for you, you can
      debug the BAT (update the version number in the EXE name in the BAT?) or you can build your
      own command using the info in the readme: 
      https://github.com/Tympan/Tympan_Rev_F_Hardware#programming-with-hardware-connection

      It's also possible to push a firmware update via the Adafruit/nRF mobile apps.  I have done
      it this way, but I prefer using the programming nest.  

      This code includes:
      * Bluetooth connection handlers
      * Generates unique advertising name specific to the module
      * Includes OTA DFU Service 
        >>  ALL TYMPAN nRF52  CODE MUST INCLUDE OTA DFU SERVICE  <<
      * Basic comms over BLE to blink LEDs for testing coms pipeline
      
 
    Original BLE servicing code by Joel Murphy for Flywheel Lab, February 2024
    Extended by Chip Audette, Benchtop Engineering, for Creare LLC, February 2024

    MIT License, use at your own risk.
 */

#define DEBUG_VIA_USB true

#define SERIAL_TO_TYMPAN Serial1                 //use this when physically wired to a Tympan. Assumes that the nRF is connected via Serial1 pins
#define SERIAL_FROM_TYMPAN Serial1               //use this when physically wired to a Tympan. Assumes that the nRF is connected via Serial1 pins

// Include the files needed by nRF52 firmware
#include <Arduino.h>
#include <bluefruit.h>
#include <Adafruit_LittleFS.h>
#include <InternalFileSystem.h>
#include "BLE_Generic.h"
#include "BLEUart_Adafruit.h"
#include "BLE_BleDis.h"
#include "BLEUart_Tympan.h"
#include "BLE_Stuff.h"
#include "LED_controller.h"
#include "AT_Processor.h"  //must already have included LED_control.h
#include "USB_SerialManager.h"


// ///////////////////////////////// Helper Functions

#define GPIO_for_isConnected 25  //what nRF pin is connected to "MISO1" net name
void setupGPIO(void) {
  pinMode(GPIO_for_isConnected, OUTPUT);
  digitalWrite(GPIO_for_isConnected, LOW);
}

LED_controller led_control;


void issueATCommand(const String &str) {  issueATCommand(str.c_str(), str.length()); }
void issueATCommand(const char *msg, unsigned int len_msg) {
  if (DEBUG_VIA_USB) {
    Serial.print(F("nRF52840 Firmware: sending to be interpreted as AT command: "));
    for (unsigned int i=0; i<len_msg; i++) Serial.print(msg[i]);
    Serial.println();
  }      
  for (unsigned int i=0; i<len_msg; i++) AT_interpreter.processSerialCharacter(msg[i]);
  AT_interpreter.processSerialCharacter('\r');  //add carriage return
}

void setup(void) {

  if (DEBUG_VIA_USB) {
    //Start up USB serial for debugging
    Serial.begin(115200);
    unsigned long t = millis();
    int timeOut = 2000; // 5 second time out before we bail on a serial connection
    while (!Serial) { // use this to allow for serial to time out
      if(millis() - t > timeOut)  break;  //break out of waiting
    }
    while (Serial.available()) Serial.read();  //clear input buffer
  
    // send some info to the user on the USB Serial Port
    Serial.println(F("*** nRF52840 Firmware: STARTING ***"));
  }

  //start the nRF's UART serial port that is physically connected to a Tympan or other microcrontroller (if used)
  Serial1.setPins(0,1);   //our nRF wiring uses Pin0 for RX and Pin1 for TX
  Serial1.begin(115200);  
  delay(500);
  while (Serial1.available()) Serial1.read();  //clear UART buffer

  //setup the GPIO pins
  setupGPIO();

  //initialize the LED display
  led_control.setLedColor(led_control.red);
  
  //setup BLE and begin
  setupBLE();    //as of Feb 2025, does not automatically start the BLE services
  //startAdv();  // start advertising

  if (DEBUG_VIA_USB) printHelpToUSB();
}


void loop(void) {

  //Respond to incoming messages on the USB serial
  if (DEBUG_VIA_USB) {
    if (Serial.available()) serialManager_processCharacter(Serial.read());
  }
  

  //Respond to incoming UART serial messages
  serialEvent(&SERIAL_FROM_TYMPAN);  //for the nRF firmware, service any messages coming in the serial port from the Tympan
  
  //Respond to incoming BLE messages
  if (bleBegun && bleConnected) { 
    //for the nRF firmware, service any messages coming in from BLE wireless link
    if (bleUart_Tympan.has_begun) BLEevent(&bleUart_Tympan, &SERIAL_TO_TYMPAN);  
    if (bleUart_Adafruit.has_begun) BLEevent(&bleUart_Adafruit, &SERIAL_TO_TYMPAN);  
  }

  //service the LEDs
  serviceLEDs(millis());

  //service the GPIO pins
  serviceGPIO(millis());
}

// ///////////////////////////////// Servicing Functions

void serviceLEDs(unsigned long curTime_millis) {
  static unsigned long lastUpdate_millis = 0;

  if (curTime_millis < lastUpdate_millis) lastUpdate_millis = 0;  //handle time wrap-around
  if ((curTime_millis - lastUpdate_millis) > 100UL) {  // how often to update
    //if (Bluefruit.connected()) {
    if (bleConnected) {
      if ((led_control.ledToFade > 0) && (led_control.ledToFade != led_control.green)) led_control.setLedColor(led_control.green);
    } else {
      if (bleBegun && Bluefruit.Advertising.isRunning()) {
        if ((led_control.ledToFade > 0) && (led_control.ledToFade != led_control.blue)) led_control.setLedColor(led_control.blue);
      } else {
        if ((led_control.ledToFade > 0) && (led_control.ledToFade != led_control.red))led_control.setLedColor(led_control.red);
      }
    }
    if(led_control.ledToFade > 0) led_control.showRGB_LED(curTime_millis);
    if (led_control.ledToFade==0) led_control.LEDsOff();
    lastUpdate_millis = curTime_millis;
  }
} 

void serviceGPIO(unsigned long curTime_millis) {
  static unsigned long lastUpdate_millis = 0;

  if (curTime_millis < lastUpdate_millis) lastUpdate_millis = 0;  //handle time wrap-around
  if ((curTime_millis - lastUpdate_millis) > 100UL) {  // how often to update
    //if (Bluefruit.connected()) {
    if (bleConnected) {
      digitalWrite(GPIO_for_isConnected, HIGH);
    } else {
      digitalWrite(GPIO_for_isConnected, LOW);
    }
    lastUpdate_millis = curTime_millis;
  }
} 

// ////////////////////////////////////////////////////////////////////// 
/*
* DataStreams: Besides the single-character and four-character modes, there are also
			data streaming modes to support specialized communication.  These special modes
			are not inteded to be invoked by a user's GUI, so they can be ignored.  To avoid
			inadvertently invoking these modes, never send characters such as 0x02, 0x03, 0x04.
			In fact, you should generally avoid any non-printable character or you risk seeing
			unexpected behavior.

			Datastreams expect the following message protocol.  Note that the message length and
			payload are sent as little endian (LSB, MSB):
			 	1.	DATASTREAM_START_CHAR 	(0x02)
				2.	Message Length (int32): number of bytes including parts-4 thru part-6
				3.	DATASTREAM_SEPARATOR 	(0x03)
				4.	Message Type (char): Avoid using the special characters 0x03 or 0x04.  (if set
							to ‘test’, it will print out the payload as an int, then a float)
				5.	DATASTREAM_SEPARATOR 	(0x03)
				6.	Payload
				7.	DATASTREAM_END_CHAR 	(0x04)

			Use RealTerm to send a 'test' message: 
			0x02 0x0D 0x00 0x00 0x00 0x03 0x74 0x65 0x73 0x74 0x03 0xD2 0x02 0x96 0x49 0xD2 0x02 0x96 0x49 0x04
				1. DATASTREAM_START_CHAR 	(0x02)
				2.	Message Length (int32): (0x000D) = 13 
				3.	DATASTREAM_SEPARATOR 	(0x03)
				4.	Message Type (char): 	(0x74657374) = 'test'
				5.	DATASTREAM_SEPARATOR 	(0x03)
				6.	Payload					(0x499602D2, 0x499602D2) = [1234567890, 1234567890]
				7.	DATASTREAM_END_CHAR 	(0x04)
*/
#define DATASTREAM_START_CHAR (0x02)
#define DATASTREAM_SEPARATOR 	(0x03)
#define DATASTREAM_END_CHAR 	(0x04)
void globalWriteBleDataToTympan(const int service_id, const int char_id, uint8_t data[], const size_t len) {
  if (len <= 0) return;

  //prepare for transmission
  char msg_type[] = "BLEDATA";
  char service_id_txt[3] = {0};
  if (service_id < 10) { service_id_txt[0] = service_id + '0'; } else { uint32_t tens = (int)(service_id/10); service_id_txt[0] = tens + '0'; service_id_txt[1] = (service_id - 10*tens) + '0'; }
  char char_id_txt[3] = {0};
  if (char_id < 10) { char_id_txt[0] = char_id + '0'; } else { uint32_t tens = (int)(char_id/10); char_id_txt[0] = tens + '0'; char_id_txt[1] = (char_id - 10*tens) + '0'; }
  uint32_t tot_len = strlen(msg_type) + 1 + strlen(service_id_txt) + 1 + strlen(char_id_txt) + 1 + len;
  
  // Copy to a byte array
  uint32_t header_len = 1+4+1;
  uint32_t footer_len = 1;
  uint32_t msg_len = header_len + tot_len + footer_len;
  uint8_t msg[msg_len];
  uint32_t next_char = 0;
  msg[next_char++] = DATASTREAM_START_CHAR;
  for (int i=0; i<4; i++) msg[next_char++] = (uint8_t)(0x000000FF & (tot_len >> (i*8)));
  msg[next_char++] = DATASTREAM_SEPARATOR;
  for (int i=0; i<strlen(msg_type); i++) msg[next_char++] = msg_type[i];
  msg[next_char++] = (uint8_t)' '; //space character
  for (int i=0; i<strlen(service_id_txt); i++) msg[next_char++] = service_id_txt[i];
  msg[next_char++] = (uint8_t)' '; //space character
  for (int i=0; i<strlen(char_id_txt); i++) msg[next_char++] = char_id_txt[i];
  msg[next_char++] = (uint8_t)' '; //space character;
  for (int i=0; i<len; i++) msg[next_char++] = data[i];
  msg[next_char++] = DATASTREAM_END_CHAR;
  if ((next_char-1) > msg_len) {
    if (DEBUG_VIA_USB) {
      Serial.print(F("globalWriteBleDataToTympan: *** ERROR ***: message length ("));
      Serial.print(next_char);
      Serial.print(F(") is larger than allocated ("));
      Serial.print(msg_len);
      Serial.println(")");
    }
  }

  //send the data
  if (DEBUG_VIA_USB) { Serial.print(F("globalWriteBleDataToTympan: Sending: ")); Serial.write(msg,msg_len);Serial.println(); }
  SERIAL_TO_TYMPAN.write(msg,msg_len);
}

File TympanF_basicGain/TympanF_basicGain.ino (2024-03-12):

/*
*   BasicGain
*
*   Created: Chip Audette, Nov 2016
*   Purpose: Process audio using Tympan by applying gain.
*
*   Blue potentiometer adjusts the digital gain applied to the audio signal.
*
*   Uses default sample rate of 44100 Hz with Block Size of 128
*
*   MIT License.  use at your own risk.
*/

//here are the libraries that we need
#include <Tympan_Library.h>  //include the Tympan Library

//create audio library objects for handling the audio
Tympan                    myTympan(TympanRev::F);  //do TympanRev::D or TympanRev::E or TympanRev::F
AudioInputI2S_F32         i2s_in;        //Digital audio *from* the Tympan AIC.
AudioEffectGain_F32       gain1, gain2;  //Applies digital gain to audio data.
AudioOutputI2S_F32        i2s_out;       //Digital audio *to* the Tympan AIC.  Always list last to minimize latency

//Make all of the audio connections
AudioConnection_F32       patchCord1(i2s_in, 0, gain1, 0);    //connect the Left input
AudioConnection_F32       patchCord2(i2s_in, 1, gain2, 0);    //connect the Right input
AudioConnection_F32       patchCord11(gain1, 0, i2s_out, 0);  //connect the Left gain to the Left output
AudioConnection_F32       patchCord12(gain2, 0, i2s_out, 1);  //connect the Right gain to the Right output


// define the setup() function, the function that is called once when the device is booting
const float input_gain_dB = 20.0f; //gain on the microphone
float vol_knob_gain_dB = 0.0;      //will be overridden by volume knob
void setup() {

  //begin the serial comms (for debugging)
  Serial.begin(115200);  delay(500);
  Serial.println("BasicGain: starting setup()...");

  //allocate the dynamic memory for audio processing blocks
  AudioMemory_F32(10); 

  //Enable the Tympan to start the audio flowing!
  myTympan.enable(); // activate the Tympan's audio module

  //Choose the desired input
  myTympan.inputSelect(TYMPAN_INPUT_ON_BOARD_MIC);     // use the on board microphones
  //myTympan.inputSelect(TYMPAN_INPUT_JACK_AS_MIC);    // use the microphone jack - defaults to mic bias 2.5V
  //myTympan.inputSelect(TYMPAN_INPUT_JACK_AS_LINEIN); // use the microphone jack - defaults to mic bias OFF

  //Set the desired volume levels
  myTympan.volume_dB(0);                   // headphone amplifier.  -63.6 to +24 dB in 0.5dB steps.
  myTympan.setInputGain_dB(input_gain_dB); // set input volume, 0-47.5dB in 0.5dB setps

  // check the volume knob
  servicePotentiometer(millis(),0);  //the "0" is not relevant here.

  Serial.println("Setup complete.");
} //end setup()


// define the loop() function, the function that is repeated over and over for the life of the device
void loop() {

  //check the potentiometer
  servicePotentiometer(millis(),100); //service the potentiometer every 100 msec

  //let's blink the LEDs!
  myTympan.serviceLEDs(millis());   //defaults to a slow toggle, add parameter 'true' to blink fast (see Tympan.h and Tympan.cpp)


} //end loop();


// ///////////////// Servicing routines

//servicePotentiometer: listens to the blue potentiometer and sends the new pot value
//  to the audio processing algorithm as a control parameter
void servicePotentiometer(unsigned long curTime_millis, unsigned long updatePeriod_millis) {
  //static unsigned long updatePeriod_millis = 100; //how many milliseconds between updating the potentiometer reading?
  static unsigned long lastUpdate_millis = 0;
  static float prev_val = -1.0;

  //has enough time passed to update everything?
  if (curTime_millis < lastUpdate_millis) lastUpdate_millis = 0; //handle wrap-around of the clock
  if ((curTime_millis - lastUpdate_millis) > updatePeriod_millis) { //is it time to update the user interface?

    //read potentiometer
	float val = float(myTympan.readPotentiometer()) / 1023.0; //0.0 to 1.0
    val = (1.0/9.0) * (float)((int)(9.0 * val + 0.5)); //quantize so that it doesn't chatter...0 to 1.0

    //send the potentiometer value to your algorithm as a control parameter
    if (abs(val - prev_val) > 0.05) { //is it different than before?
      prev_val = val;  //save the value for comparison for the next time around

      //choose the desired gain value based on the knob setting
      const float min_gain_dB = -20.0, max_gain_dB = 40.0; //set desired gain range
      vol_knob_gain_dB = min_gain_dB + (max_gain_dB - min_gain_dB)*val; //computed desired gain value in dB

      //command the new gain setting
      gain1.setGain_dB(vol_knob_gain_dB);  //set the gain of the Left-channel gain processor
      gain2.setGain_dB(vol_knob_gain_dB);  //set the gain of the Right-channel gain processor
      Serial.print("servicePotentiometer: Digital Gain dB = "); Serial.println(vol_knob_gain_dB); //print text to Serial port for debugging
    }
    lastUpdate_millis = curTime_millis;
  } // end if
} //end servicePotentiometer();

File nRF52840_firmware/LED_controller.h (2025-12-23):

// ////////////////////////////////////////////////////////////////////////////////////////////////////////////////
//
// This code controls the LED that is under the control of the nRF52840.
//
// MIT License.  Use at your own risk.
//
// /////////////////////////////////////////////////////////////////////////////////////////////////////////////////

#ifndef LED_CONTROL_H
#define LED_CONTROL_H

#define LED_0 14  // red
#define LED_1 12  // blue
#define LED_2 15  // green

// LED fade stuff
#define FADE_DELAY_SLOW 50
#define FADE_DELAY_FAST 5
#define FADE_RATE 8
#define FADE_MAX 127
#define FADE_MIN 255

class LED_controller {
  public:
    LED_controller() {
      setupLEDs();
    };
    const int red = LED_0;
    const int blue = LED_1;
    const int green = LED_2;
    unsigned int fadeDelay = FADE_DELAY_SLOW;
    int fadeRate = 0 - FADE_RATE;
    int fadeValue = FADE_MIN;
    int ledToFade = blue;
    unsigned long lastShowTime;
    
    void setupLEDs(void) { for(int i=0; i<3; i++)  pinMode(ledPin[i],OUTPUT); }
    void disableLEDs(void) { ledToFade = 0; LEDsOff(); }
    void LEDsOff(void ){ 
      fadeValue = FADE_MIN; // keep in bounds
      for(int i=0; i<3; i++) analogWrite(ledPin[i],fadeValue);
    }

    void setLedColor(int color_ind) {
      if (color_ind != ledToFade) LEDsOff();
      if ((color_ind == red) || (color_ind == blue) || (color_ind == green)) {
        ledToFade = color_ind;
        fadeDelay = FADE_DELAY_SLOW;
        lastShowTime = millis();
      }
    }

    void showRGB_LED(unsigned long m) {
      if (m < lastShowTime) lastShowTime = 0; //handle the case when time wraps around
      if ((ledToFade != red) && (ledToFade != green) && (ledToFade != blue)) return; //leds are disabled

      if(m > lastShowTime + fadeDelay) { //is it time to update?
        lastShowTime = m; // keep time

        fadeValue += fadeRate;  // adjust brightness
        if(fadeValue >= FADE_MIN){ // LEDs are Common Anode
          fadeValue = FADE_MIN; // keep in bounds
          fadeRate = 0 - FADE_RATE; // change direction
        } else if(fadeValue <= FADE_MAX){ // LEDs are Common Anode
          fadeValue = FADE_MAX; // keep in bounds
          fadeRate = 0 + FADE_RATE; // change direction
        }
        analogWrite(ledToFade,fadeValue);
      }
    }

  private:
    int ledPin[3] = {LED_0, LED_1, LED_2}; // red, blue, green
  
};




#endif

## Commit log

2024-01-19 Initial Commit: Work In Progress
    Changes made to version up to Rev F:
    - Replace BC127 with MDBT50Q-1MV2
    - Add functional components for radio module
    - New pin assignments for existing nets
    - Added nets and pin assignments for I2S
    [MDBT50Q-1MV2.step, Tympan_Rev_F.kicad_pcb, Tympan_Rev_F.kicad_sch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]
2024-01-19 Added SPI
    Selected pins to bring SPI connection to the BLE moudule
    [Tympan_Rev_F.kicad_pcb, Tympan_Rev_F.kicad_sch]
2024-01-19 Added pdf of schematic
    [Tympan_Rev_F.kicad_sch]
2024-01-25 Swapped the SPI bus
    moved nRESET pin to open up SPI_1 pins for exclusive connection to the BT module.
    This frees up our existing SPI bus breakout for use as SPI or as GPIO
    [Tympan_Rev_F.kicad_sch]
2024-02-07 minor edit save
    [Tympan_Rev_F.kicad_pcb]
2024-02-08 First pass at routing
    Have all circuits routed exept for nRF52 program header. Got to figure out the footprint and placement.
    [BAT-HLD-012-SMT.step, Tympan_Rev_F.kicad_pcb, Tympan_Rev_F.kicad_sch]
2024-02-12 first pass at laying out the J-Link interface
    [Tympan_Rev_F.kicad_pcb, Tympan_Rev_F.kicad_sch]
2024-02-13 Passing DRC Getting ready for production
    Added a file for the nRF52 radio module programmer. This will use pogo pins.
    [BAT-HLD-012-SMT.step, MDBT50Q-1MV2.step, Tympan nRF52 Programmer.kicad_pcb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]
2024-02-16 Production Files Approved
    [Tympan nRF52 Programmer-B_Cu.gbr, Tympan nRF52 Programmer-B_Mask.gbr, Tympan nRF52 Programmer-Edge_Cuts.gbr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]
2024-02-20 Finished design of nRF52 Programmer board
    [Tympan nRF52 Programmer.kicad_pcb, Tympan nRF52 Programmer.kicad_sch]
2024-02-21 Updating ReadMe
    [Tympan_Rev_F.kicad_pcb]
2024-03-08 pushing meta data and case files
    [Pin Assignments Accross Revs.ods, Pin Assignments Accross Revs.xlsx, Tympan Rev F Bottom.stl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]
2024-03-12 Adding test firmware
    [Pin Assignments Accross Revs.ods]
2024-03-25 Update schematic pdf
    [Tympan_Rev_F.kicad_sch]
2024-03-28 update pin assignments across revs
    [Pin Assignments Accross Revs.xlsx]
2024-09-04 Added SDS and Lithium Battery Test Summary documentation
2024-09-04 Add battery test results for UN38.3 compliance
2024-09-05 Revised Rev-E Case
    - Allowed for a top-mounted power switch.
    - Recentered the opening for the reset switch.
    - Increased the height inside the case, to allow more room for the battery. I
    - Wrapped the battery in adhesive backed 1/32" foam.
    - Removed the belt clip holes which added too much thickness to the case. - Added lanyard loop
    - Opened up the SD card slot and centered it.
    - Updated the Tympan Rev-F label.
    Also added alternate case design for belt clip mounting holes.
    [7146_Tympan_Rev-F_Bottom_Case.STEP, 7146_Tympan_Rev-F_Bottom_Case_Belt_Mount.STEP, 7146_Tympan_Rev-F_Top_Case.STEP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]
2024-09-09 Case update
    - Deepened heat insert holes to accommodate Joel's inserts
    - Added board supports for PCB
    - Filled in label area
    [7146_Tympan_Rev-F_Bottom_Case.STEP, 7146_Tympan_Rev-F_Top_Case.STEP]
2024-09-09 Generated STL files of latest case design. Update readme
    [7146_Tympan_Rev-F_Bottom_Case.stl, 7146_Tympan_Rev-F_Top_Case.stl]
2024-09-11 Revised case
    Added ramp to led holes to work better with FDM scaffolding.
    [7146_Tympan_Rev-F_Bottom_Case.STEP, 7146_Tympan_Rev-F_Bottom_Case_NoLabel.STEP, 7146_Tympan_Rev-F_Top_Case.STEP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]
2024-09-16 Pushing latest STL files
    [7146_Tympan_Rev-F_Bottom_Case.stl, 7146_Tympan_Rev-F_Top_Case.stl]
2024-09-16 Optimized for FDM printing.
    [7146_Tympan_Rev-F_Bottom_Case.STEP, 7146_Tympan_Rev-F_Bottom_Case_Belt_Mount.STEP, 7146_Tympan_Rev-F_Top_Case.STEP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]
2024-09-16 Moving files for case with belt mount
    [7146_Tympan_Rev-F_Bottom_Case_Belt_Mount.STEP, 7146_Tympan_Rev-F_Top_Case_Belt_Mount.STEP]
2024-09-24 Revised enclosure
    Added thickness to cutouts for screwdriver access.
    [7146_Tympan_Rev-F_Bottom_Case.STEP, 7146_Tympan_Rev-F_Bottom_Case.stl, 7146_Tympan_Rev-F_Bottom_Case_Belt_Mount.STEP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]
2025-02-05 nRF52840_firmware: set MAC, set BEGIN, add BLENOTIFY and BLEWRITE. Works but still testing.
    [nRF52840_firmware.ino]
2025-02-06 nRF52840_firmware: fix bug where it wouldn't reset the rx_mode
    [AT_Processor.h]
2025-02-06 nRF52840_firmware: added preset for battery service
2025-02-07 nURF52840_firmware: add ability to change Device Information Service data
2025-02-10 nRF52840_firmware: receive value from BLE Button Service
2025-02-12 nRF52840_firmware: fix bug in setting MAC (and adjust error messages)
    [AT_Processor.h]
2025-02-13 nRF52840_firmware: replace HEX and DAT. candidate release v040
    [nRF52840_firmware.ino]
2025-02-14 nRF52840_firmware: fix typo. new HEX and DAT
    [BLE_Stuff.h]
2025-02-27 nRF52840_firmware: add 3rd characteristic to custom LED Button service
2025-02-27 Adding SW CAD files
    [86375K131_NEOPRENE_031_THK.SLDPRT, 90107A002_316 Stainless Steel Washer_Sz-0.SLDPRT, 90258A121_Phillips Oval Head Screws.SLDPRT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]
2025-02-27 nRF52840_firmware: complete LED Button Service 3rd characteristic
2025-07-03 Update README.md regarding speed of UART comms
2025-10-29 Firmware: AT_Processor: fix bug in getName where it doesn't clear the message
    [AT_Processor.h, BLE_Stuff.h]
2025-12-05 Firmware: Bug fix: BLE name is based on ID again. Up rev to v0.4.2
    [BLE_Stuff.h]
2025-12-23 adding component renders for 3d model
    Currently missing:
    MEMS microphones
    Power Switch
    Teensy 4.1 is rendering with TH pins. It's ugly, but the USB and SD card are accurately placed.
    [BAT-HLD-012-SMT.step, MDBT50Q-1MV2.step, Tympan_Rev_F.kicad_pcb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]
2025-12-23 added PROGRAM switch part
    [Tympan_Rev_F.kicad_pcb]
2025-12-26 Added component renders
    [Tympan_Rev_F.kicad_pcb]
